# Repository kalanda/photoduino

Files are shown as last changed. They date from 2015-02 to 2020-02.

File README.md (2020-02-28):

           _                          _       _             
          | |           _            | |     (_)            
     ____ | |__   ___ _| |_  ___   __| |_   _ _ ____   ___  
    |  _ \|  _ \ / _ (_   _)/ _ \ / _  | | | | |  _ \ / _ \ 
    | |_| | | | | |_| || |_| |_| ( (_| | |_| | | | | | |_| |
    |  __/|_| |_|\___/  \__)\___/ \____|____/|_|_| |_|\___/ 
    |_|  THE OPENSOURCE CAMERA CONTROLLER BASED ON ARDUINO                                                         

https://kalanda.github.io/photoduino/

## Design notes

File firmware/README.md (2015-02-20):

           _                          _       _             
          | |           _            | |     (_)            
     ____ | |__   ___ _| |_  ___   __| |_   _ _ ____   ___  
    |  _ \|  _ \ / _ (_   _)/ _ \ / _  | | | | |  _ \ / _ \ 
    | |_| | | | | |_| || |_| |_| ( (_| | |_| | | | | | |_| |
    |  __/|_| |_|\___/  \__)\___/ \____|____/|_|_| |_|\___/ 
    |_|  THE OPENSOURCE CAMERA CONTROLLER BASED ON ARDUINO                                                         

#Photoduino firmware

Firmware for Photoduino Shield as Arduino Sketch.
[Download firmware release 1.1](http://sourceforge.net/projects/photoduino/files/firmware/photoduino.shield.firmware.v.1.1.zip/download)

* * *

##Firmware changelog:

## release 1.1

 - New sensor type "None" which is always triggered. This is useful when you want to use solenoid valve control without any barrier sensor.
 - Now the laser is always on if the "Device Type" is equal to "Laser" (laser will turn off when the photo is taken as usual)
 - Some changes related to the remote software
 - New language file with Francais translation of menus (Thanks to Guy Renou)

## release 1.0

 - Compatible with the new desktop software for remote control of Photoduino using USB port [Photoduino Remote Software](https://sourceforge.net/projects/photoduino/files/software/)
 - New language file with Italian translation of menus (Thanks to Andrea Candolini)

##release 0.10 

 - All files use ".ino" file extension for the 1.0 Arduino environment
 - Fixed some compile errors on Arduino 1.0 environment
 - Now uses progmem for allocating strings in program memory
 - Reduced compiled code size
 - New progress bar interface element
 - Added confirmation message when you reset config in any execution mode to avoid accidental losses
 - Fixed some spelling errors
 - Now the shutterlag is a common system parameter because it depends of the camera model and is the same in all the run modes. 
 - Now "Use flash1" and "Use flash2" are system parameters. If p.e. UseFlash2 is "NO", then in the config menus of all run modes you will don't see the "flash2 pretime".
 - Now, the language messages are in separated files for each language to improve future translations.
 - Mirror lockup timeout is now configurable through the system menu.
 - New system parameter "DEVICE TYPE" determines the use of the Device port like laser, electrovalve, ...
 - A big new functionality of control electro-valve or solenoid valve. Docs soon.
 - New key input holding A+B buttons to use it in numeric sensor tuning to match sensor and limit values to equal.

##release 0.9 

 - Added new "Mirror lockup" functionality in all sensor modes
 - Added new "Numeric mode" for tuning sensor limit with more precision. 
 - Added compatibility with ArduinoMega by "#define BOARD_ARDUINO_MEGA".
 - Default interval time is now 1 second instead 1000 miliseconds because 
   is more common used.
 - Added a compile value to define the pulse width for shooting the flash.
 - Some other minor fixes and code reviews.  
 
##release 0.8

 - Bug fixed on some cameras like canon 50d with prebulb yes. 
 
##release 0.7 

 - Bug fixed on shutterEnd with prebulb yes. 
  
##release 0.6 

 - New mode "Flash slave" uses the LDR sensor to shoot the flashes like a 
   slave flash.
 - Now all text messages are defines to make posible the i18n. 
   Current available languages are spanish and english
 - Fixed a bug with cycles on intervalmode
 
##release 0.5 

 - Now each sensor have a run mode and custom config
 - New parameter "cycles" also on sensor trigger modes
 - New parameter "intercicle time" added on sensor trigger modes for wait
   between cycles to let the camera time to process the photo or avoid shoots
   by noise on sensors.
 - Removed all "exit" options from menus to reduce code size and simplify. 
   Use hold-A-button to exit.
 - Added power on/off control of a laser connected to the RESERVED port. 
   Laser is set power-off before open the camera shutter.
 - Re-organization of .pde files
 - Many code improvements to reduce code size and enhace the organization
 
##release 0.4

 - Keyboard reading is completly re-writed code to enhance control and use 
   debounce and hold time
 - Revision of code comments
 - added reference of default shutterlag times for canon DSLR cameras
 - (function setSensorLimit) now uses two buttons for up and down the value
  
##release 0.3

 - (function setIntValue) Bug fixed when sets numeric values higher than 59999 
 - (function setIntValue) Numeric values now uses two buttons for up and down 
 - (function setIntValue) Now shows the measure units
 - (PINS_BTN_A and PINS_BTN_B) Interchanged to be the same reference in silkscreen
 - (function keyScan) Bug fixed
 
##release 0.2

 - New file organization
 - Various improvements
 - Configuration backup on eeprom

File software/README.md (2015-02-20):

           _                          _       _             
          | |           _            | |     (_)            
     ____ | |__   ___ _| |_  ___   __| |_   _ _ ____   ___  
    |  _ \|  _ \ / _ (_   _)/ _ \ / _  | | | | |  _ \ / _ \ 
    | |_| | | | | |_| || |_| |_| ( (_| | |_| | | | | | |_| |
    |  __/|_| |_|\___/  \__)\___/ \____|____/|_|_| |_|\___/ 
    |_|  THE OPENSOURCE CAMERA CONTROLLER BASED ON ARDUINO                                                         

#Photoduino remote

This is the repository for souce code of Photoduino Remote, a desktop application for remote control of Photoduino hardware using the USB cable.

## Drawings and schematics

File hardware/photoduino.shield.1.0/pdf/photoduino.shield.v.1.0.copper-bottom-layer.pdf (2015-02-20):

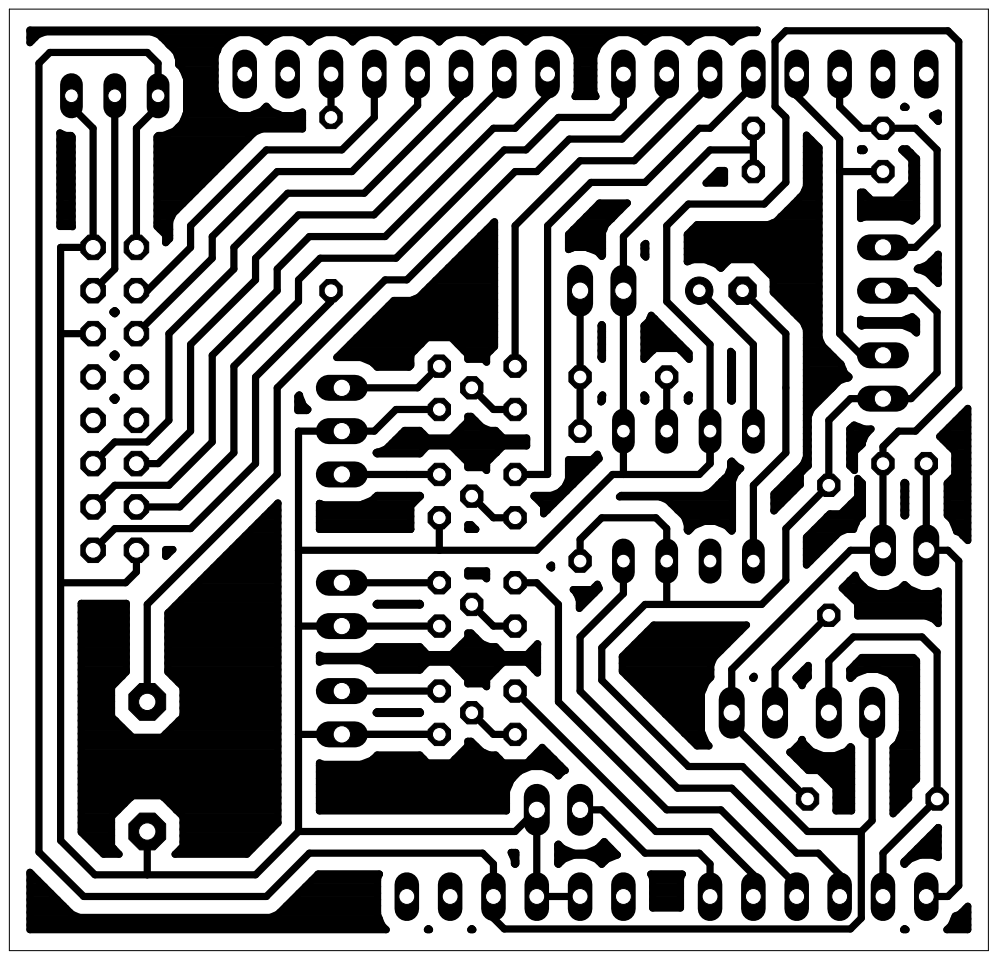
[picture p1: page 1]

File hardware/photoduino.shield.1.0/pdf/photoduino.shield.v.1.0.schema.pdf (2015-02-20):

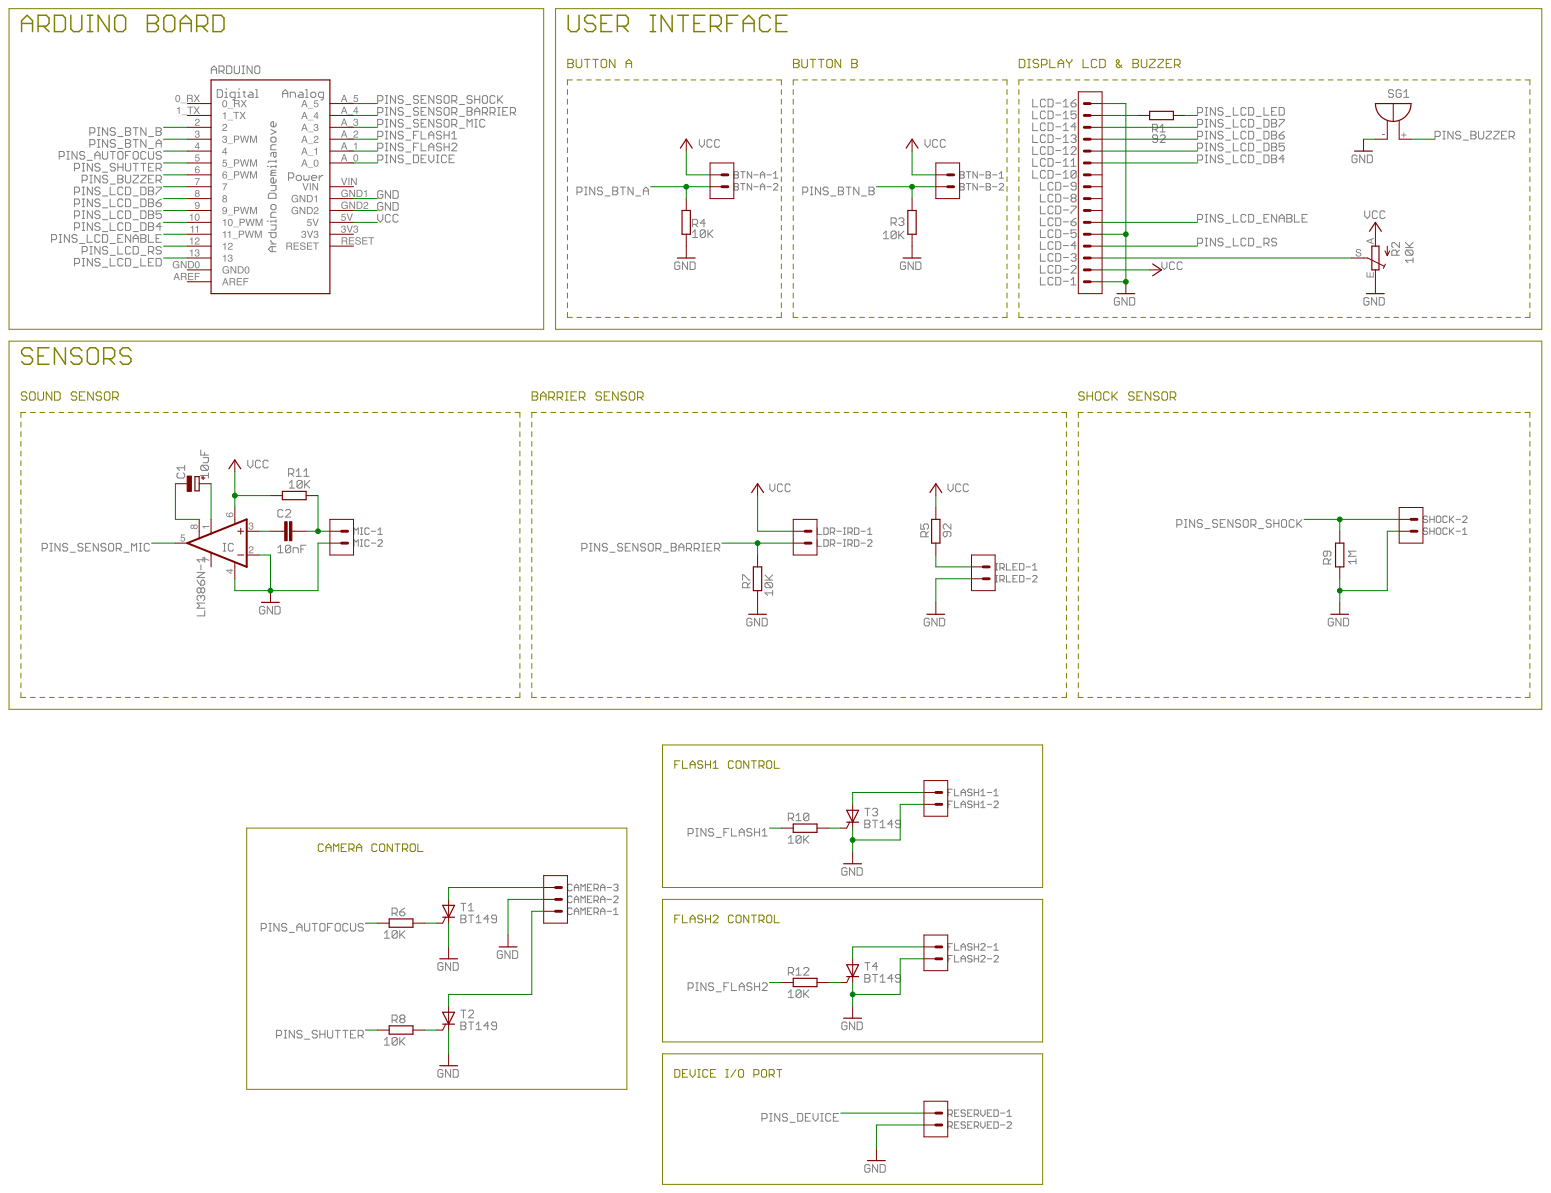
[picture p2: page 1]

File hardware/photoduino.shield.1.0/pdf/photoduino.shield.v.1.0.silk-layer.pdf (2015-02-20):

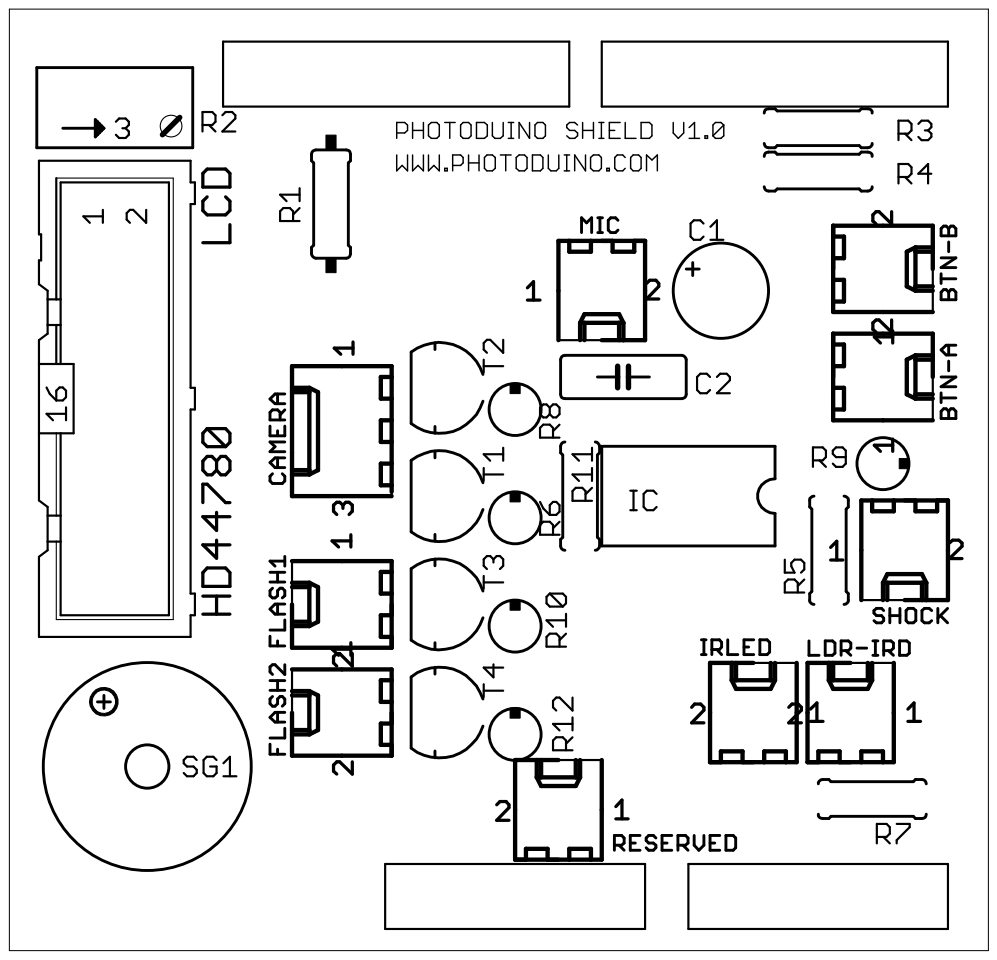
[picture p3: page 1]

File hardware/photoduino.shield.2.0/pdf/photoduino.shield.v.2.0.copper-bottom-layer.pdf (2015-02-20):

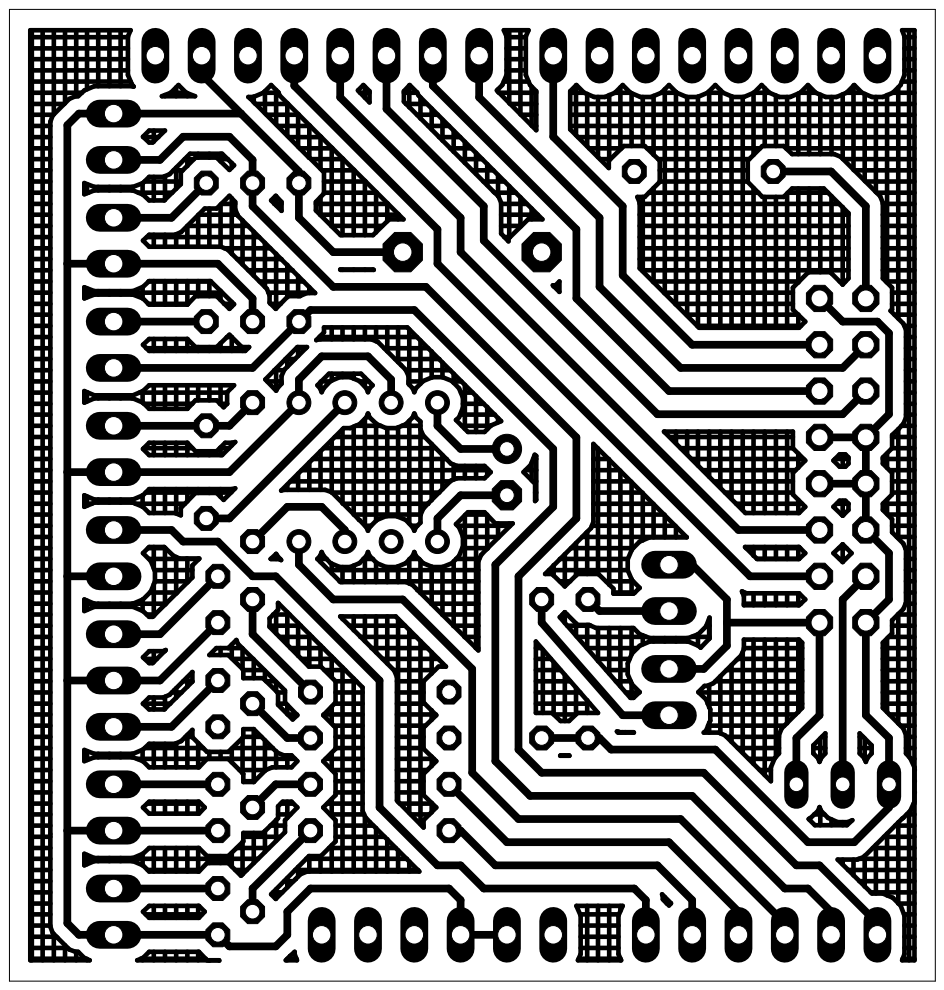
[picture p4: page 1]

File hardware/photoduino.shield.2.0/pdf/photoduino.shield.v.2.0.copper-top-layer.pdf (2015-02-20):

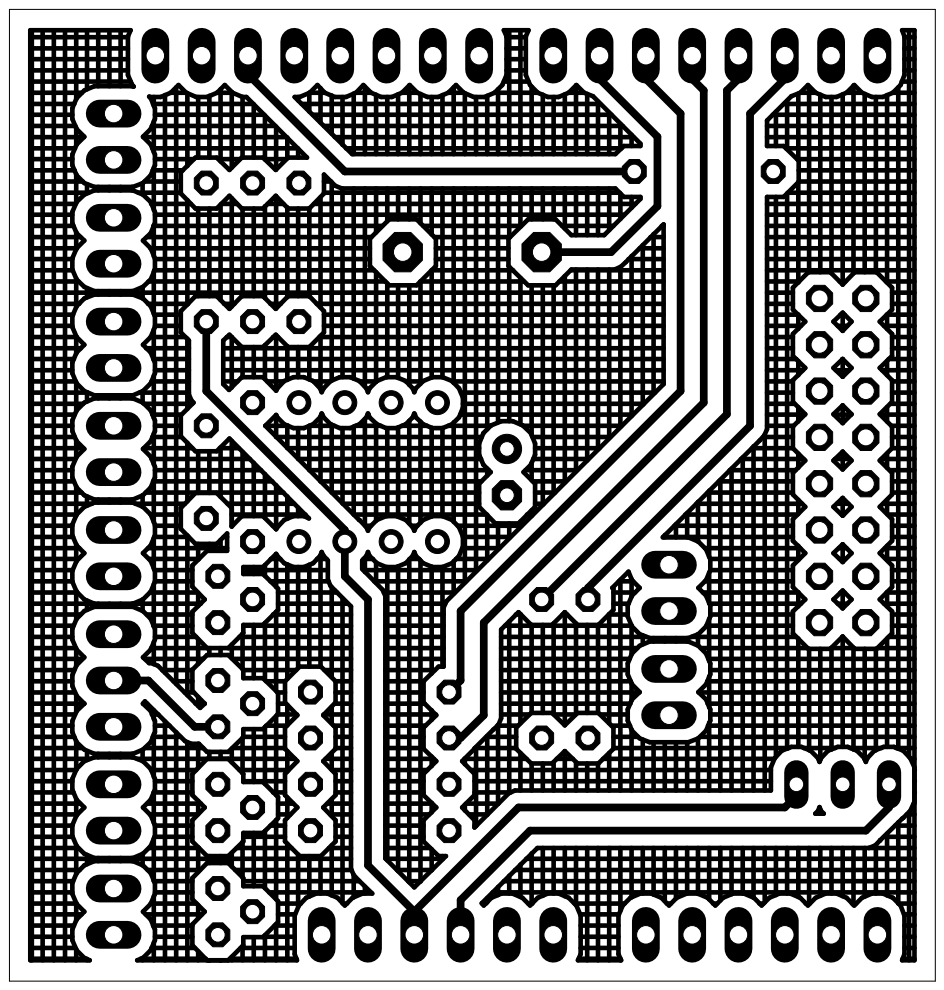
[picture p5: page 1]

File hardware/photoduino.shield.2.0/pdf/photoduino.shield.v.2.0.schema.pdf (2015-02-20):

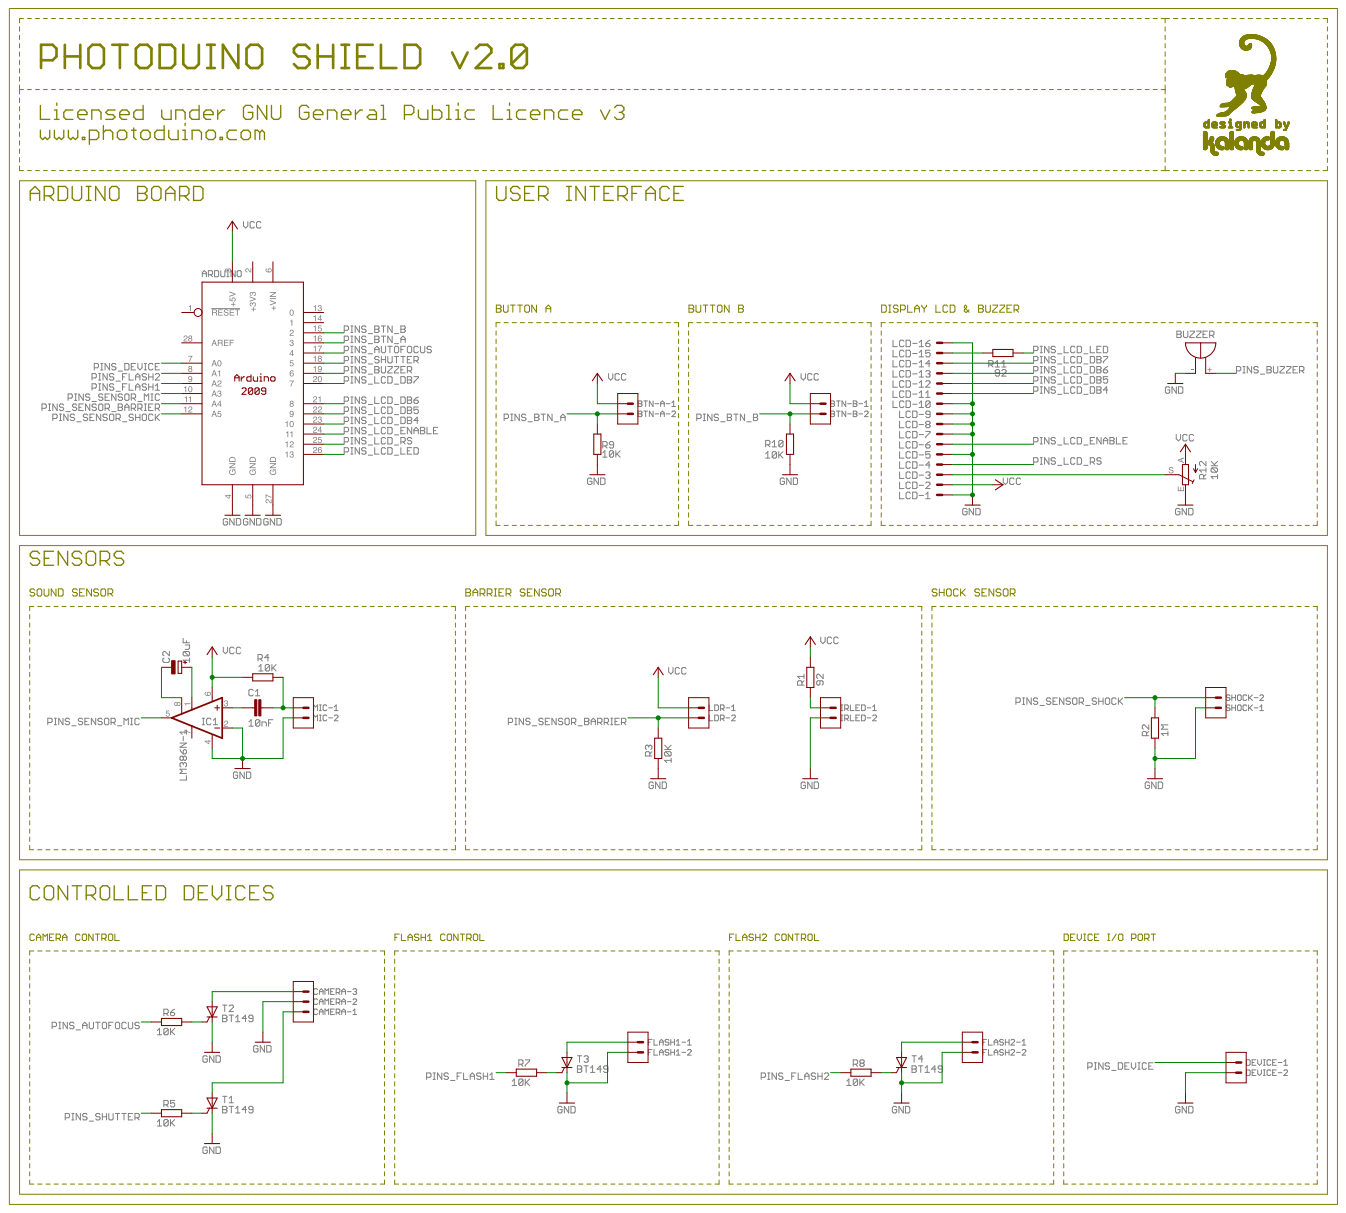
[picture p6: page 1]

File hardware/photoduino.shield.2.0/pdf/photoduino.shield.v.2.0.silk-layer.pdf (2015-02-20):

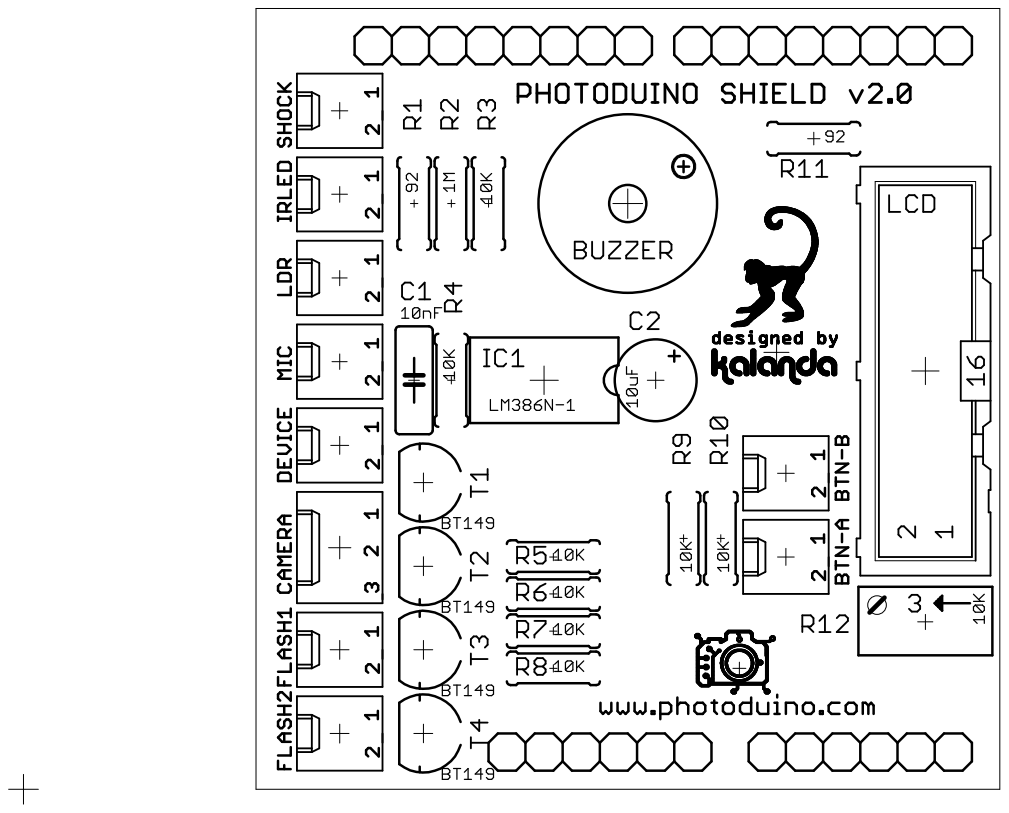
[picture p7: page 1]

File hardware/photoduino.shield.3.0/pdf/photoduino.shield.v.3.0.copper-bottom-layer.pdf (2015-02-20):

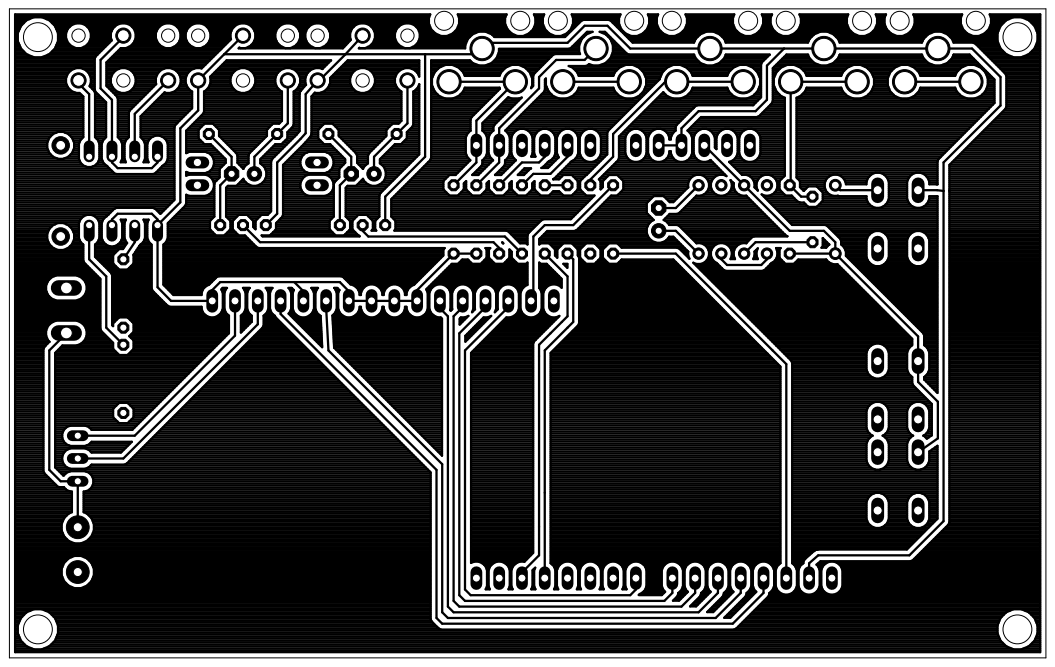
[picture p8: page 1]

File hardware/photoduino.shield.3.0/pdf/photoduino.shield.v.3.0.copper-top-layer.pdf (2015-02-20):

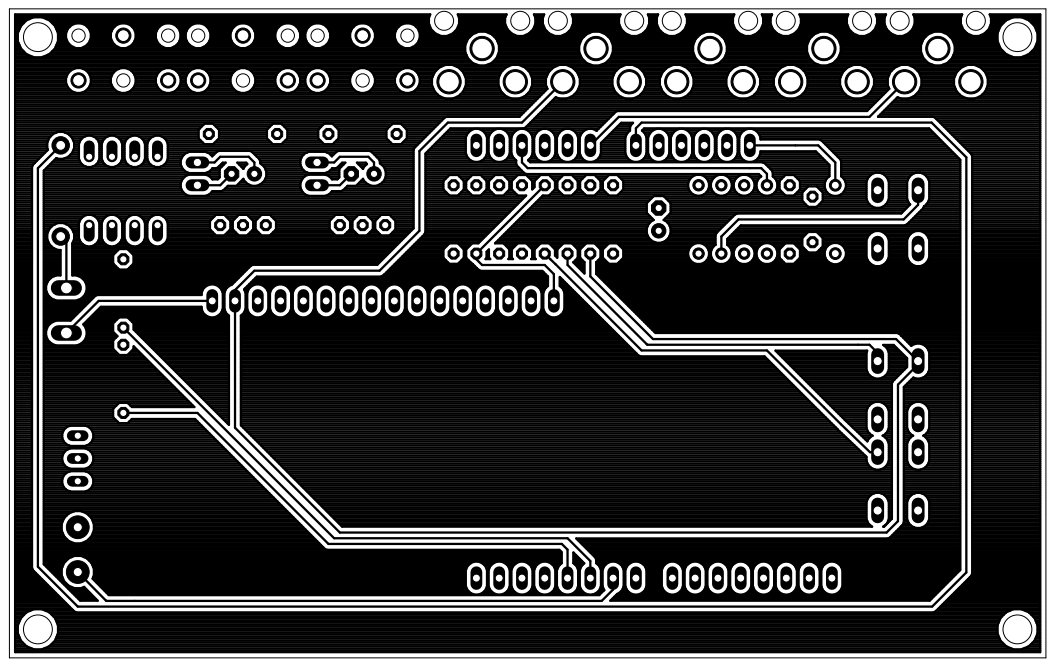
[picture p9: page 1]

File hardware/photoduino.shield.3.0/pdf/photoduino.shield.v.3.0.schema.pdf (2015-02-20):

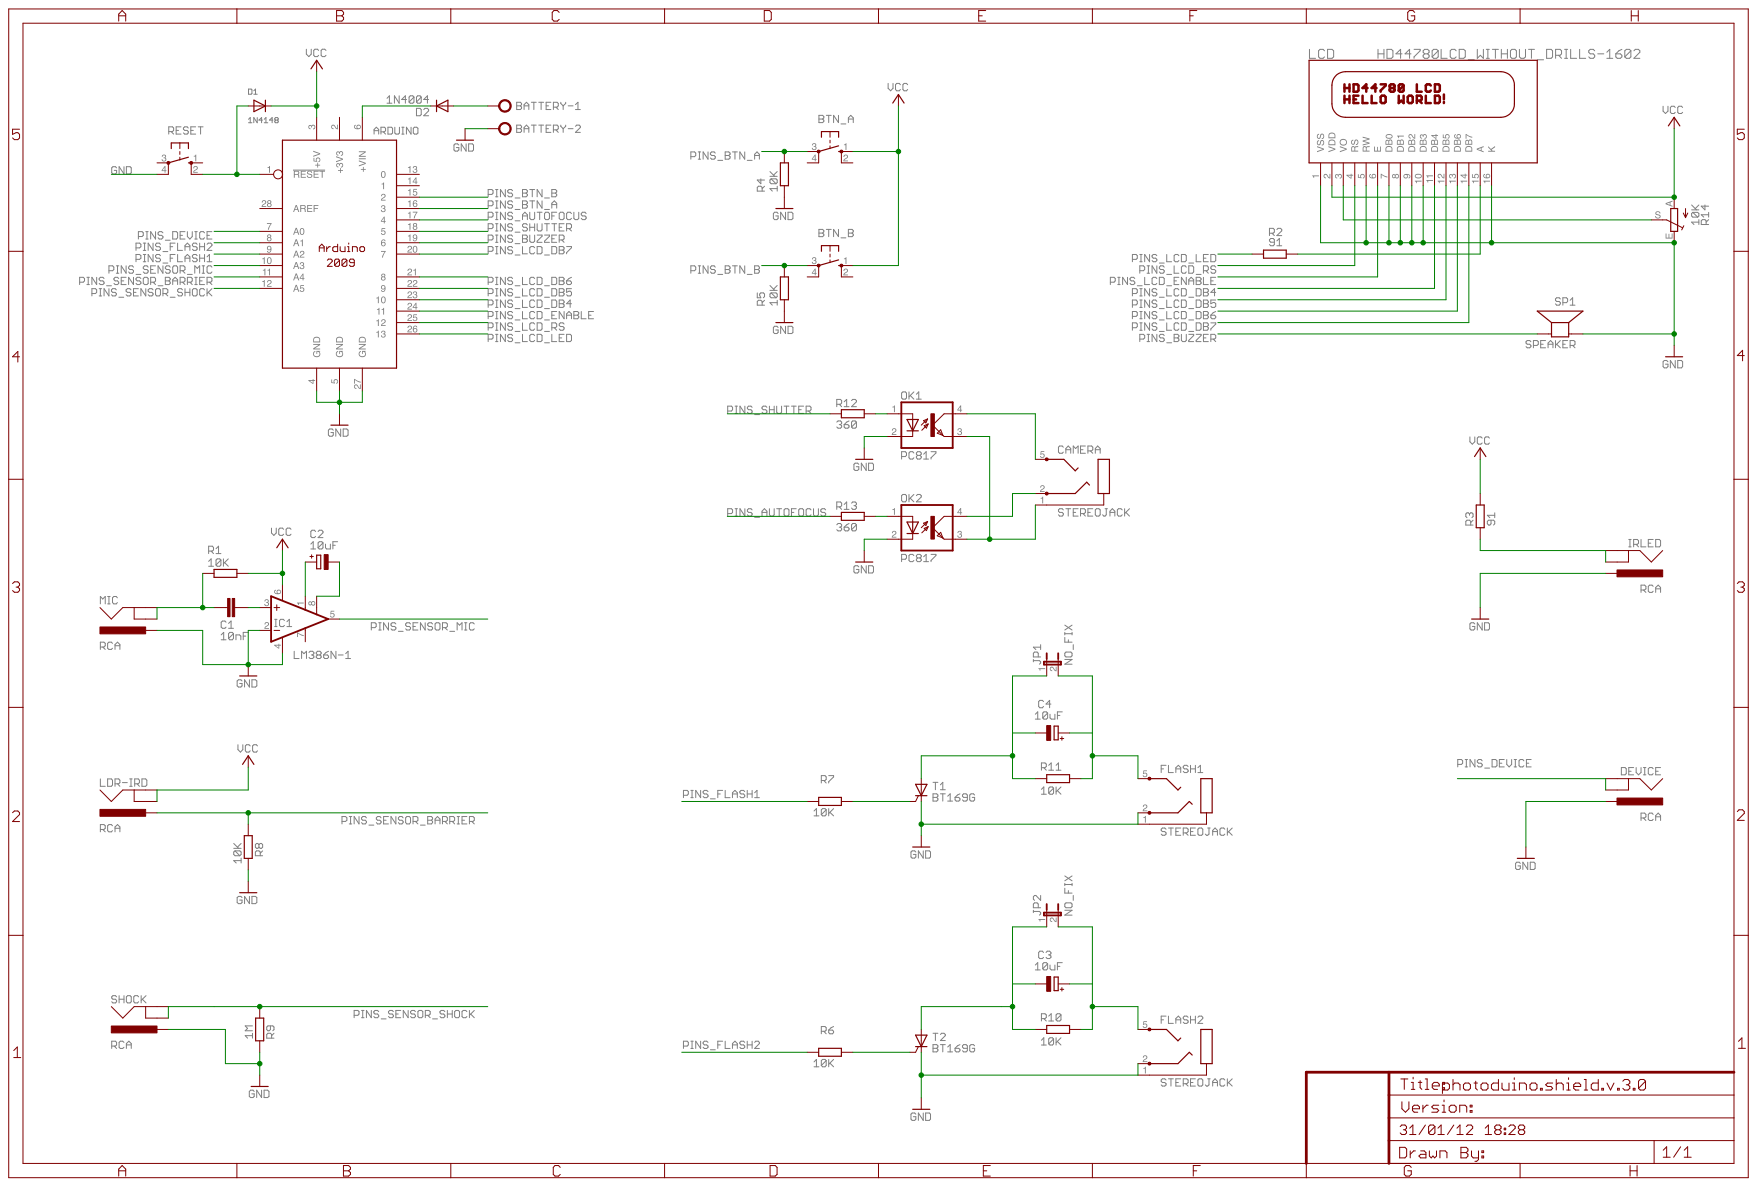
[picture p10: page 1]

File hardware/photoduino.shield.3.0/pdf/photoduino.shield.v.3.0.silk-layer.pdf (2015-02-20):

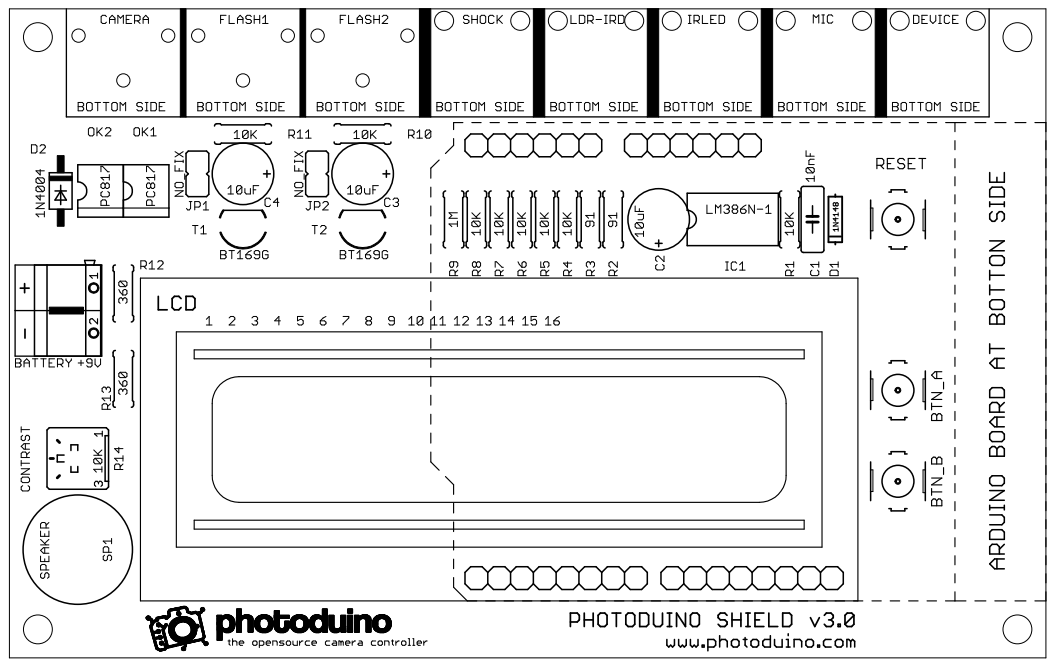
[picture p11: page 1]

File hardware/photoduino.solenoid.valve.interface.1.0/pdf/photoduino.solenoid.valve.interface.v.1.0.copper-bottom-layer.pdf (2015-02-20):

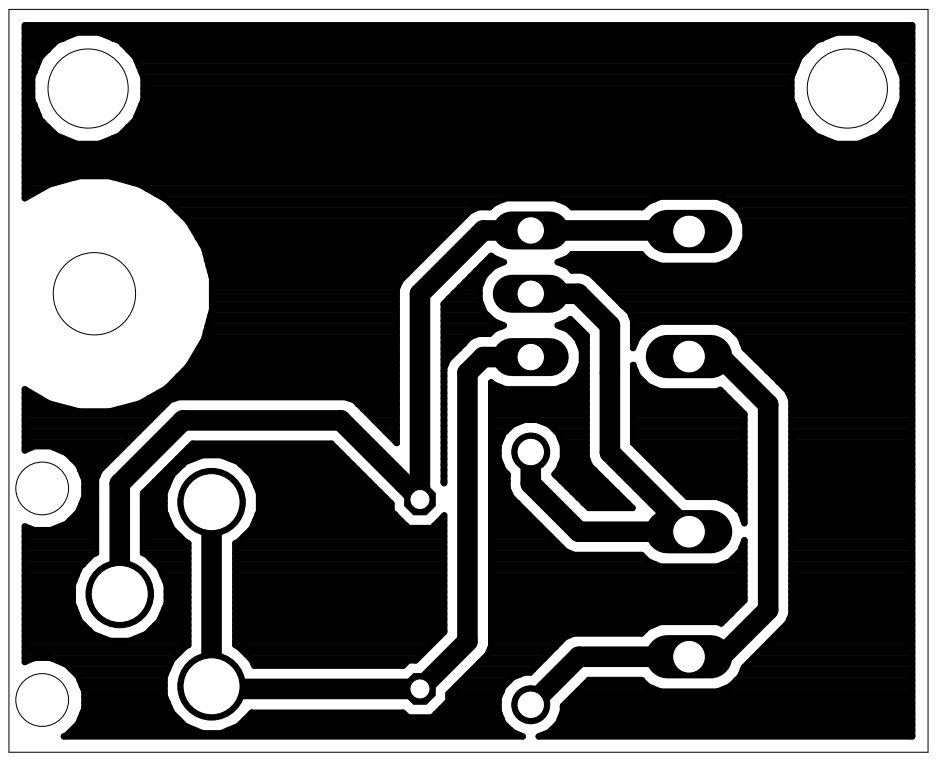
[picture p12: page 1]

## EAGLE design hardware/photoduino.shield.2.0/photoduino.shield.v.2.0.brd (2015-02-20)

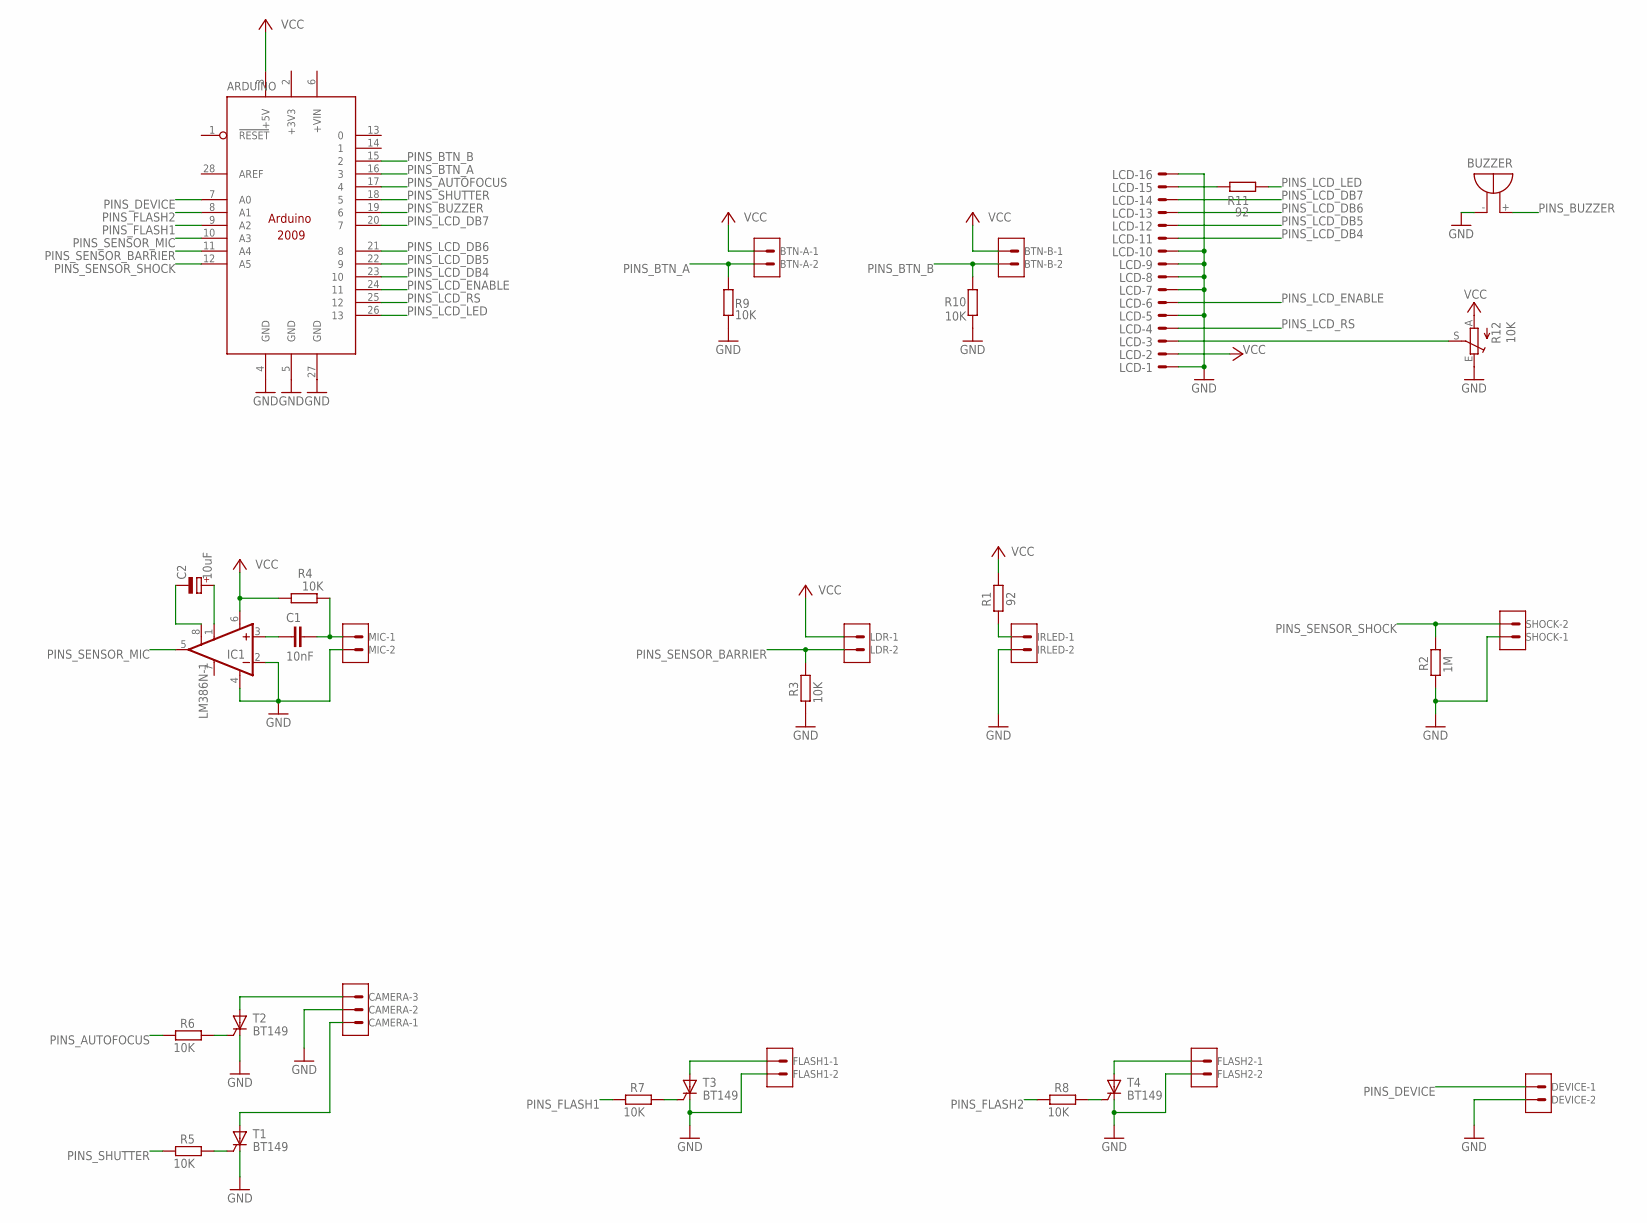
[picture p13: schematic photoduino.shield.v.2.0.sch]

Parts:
ARDUINO: ARDUINO2009_11; ARDUINO2009_1
BTN-A: 22-27-2021-02; 6410-02
BTN-B: 22-27-2021-02; 6410-02
BUZZER: F/TMB
C1: 10nF; C050-025X075
C2: 10uF; E2,5-6
CAMERA: 22-27-2031-03; 6410-03
DEVICE: 22-27-2021-02; 6410-02
FLASH1, FLASH2: 22-27-2021-02; 6410-02
IC1: LM386N-1; DIL08
IRLED: 22-27-2021-02; 6410-02
LCD: ML16E; ML16
LDR: 22-27-2021-02; 6410-02
LOGO: LOGOKALANDA
MIC: 22-27-2021-02; 6410-02
R1, R11: 92; 0207/7
R2: 1M; 0207/7
R3, R4, R5, R6, R7, R8, R9, R10: 10K; 0207/7
R12: 10K; RJ9W
SHOCK: 22-27-2021-02; 6410-02
T1, T2, T3, T4: BT149; TO92-4

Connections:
+3V3: ARDUINO.2 (+3V3)
GND: ARDUINO.4 (GND), ARDUINO.5 (GND), ARDUINO.27 (GND), BUZZER.-, CAMERA.2, DEVICE.2, FLASH1.2, FLASH2.2, IC1.2 (-IN), IC1.4 (GND), IRLED.2, LCD.1, LCD.5, LCD.7, LCD.8, LCD.9, LCD.10, LCD.16, MIC.2, R2.2, R3.2, R9.1, R10.2, R12.E, SHOCK.1, T1.C, T2.C, T3.C, T4.C
LCD_CONTRAST: LCD.3, R12.S
unnamed: IRLED.1, R1.2
unnamed: C1.1, IC1.3 (+IN)
unnamed: C1.2, MIC.1, R4.1
unnamed: R7.1, T3.G
unnamed: R8.1, T4.G
unnamed: CAMERA.3, T2.A
unnamed: R6.1, T2.G
unnamed: R5.1, T1.G
unnamed: C2.+, IC1.1 (GAIN)
unnamed: FLASH2.1, T4.A
unnamed: FLASH1.1, T3.A
unnamed: C2.-, IC1.8 (GAIN)
unnamed: LCD.15, R11.2
PINS_AUTOFOCUS: ARDUINO.17 (4), R6.2
PINS_BTN_A: ARDUINO.16 (3), BTN-A.2, R9.2
PINS_BTN_B: ARDUINO.15 (2), BTN-B.2, R10.1
PINS_BUZZER: ARDUINO.19 (6), BUZZER.+
PINS_DEVICE: ARDUINO.7 (A0), DEVICE.1
PINS_FLASH1: ARDUINO.9 (A2), R7.2
PINS_FLASH2: ARDUINO.8 (A1), R8.2
PINS_LCD_DB4: ARDUINO.23 (10), LCD.11
PINS_LCD_DB5: ARDUINO.22 (9), LCD.12
PINS_LCD_DB6: ARDUINO.21 (8), LCD.13
PINS_LCD_DB7: ARDUINO.20 (7), LCD.14
PINS_LCD_ENABLE: ARDUINO.24 (11), LCD.6
PINS_LCD_LED: ARDUINO.26 (13), R11.1
PINS_LCD_RS: ARDUINO.25 (12), LCD.4
PINS_SENSOR_BARRIER: ARDUINO.11 (A4), LDR.2, R3.1
PINS_SENSOR_MIC: ARDUINO.10 (A3), IC1.5 (OUT)
PINS_SENSOR_SHOCK: ARDUINO.12 (A5), R2.1, SHOCK.2
PINS_SHUTTER: ARDUINO.18 (5), R5.2
SHUTTER: CAMERA.1, T1.A
VCC: ARDUINO.3 (+5V), BTN-A.1, BTN-B.1, IC1.6 (VS), LCD.2, LDR.1, R1.1, R4.2, R12.A

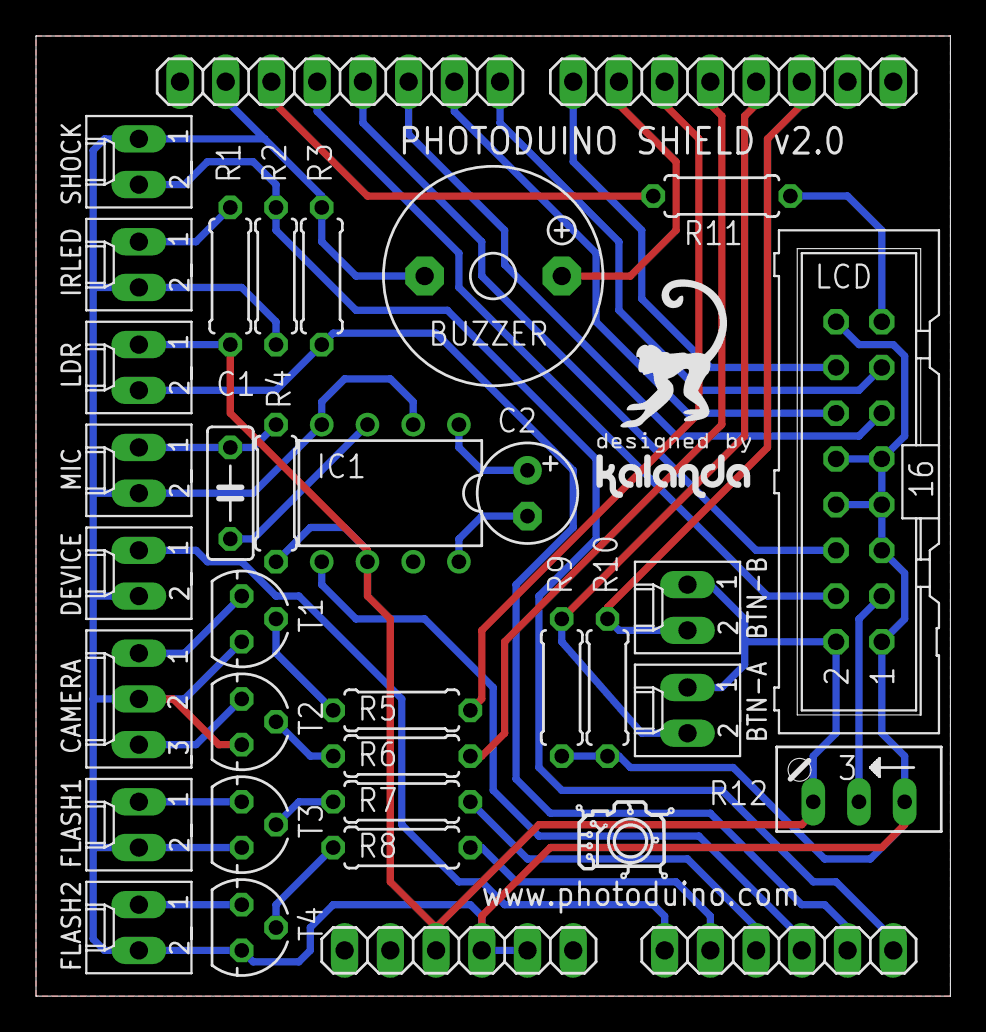
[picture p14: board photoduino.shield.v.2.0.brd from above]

Board: 2 copper layers, 50.8 x 53.3 mm, 34 parts (0 on the bottom side), 35 nets.

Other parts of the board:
U$1: LOGOPHOTODUINO

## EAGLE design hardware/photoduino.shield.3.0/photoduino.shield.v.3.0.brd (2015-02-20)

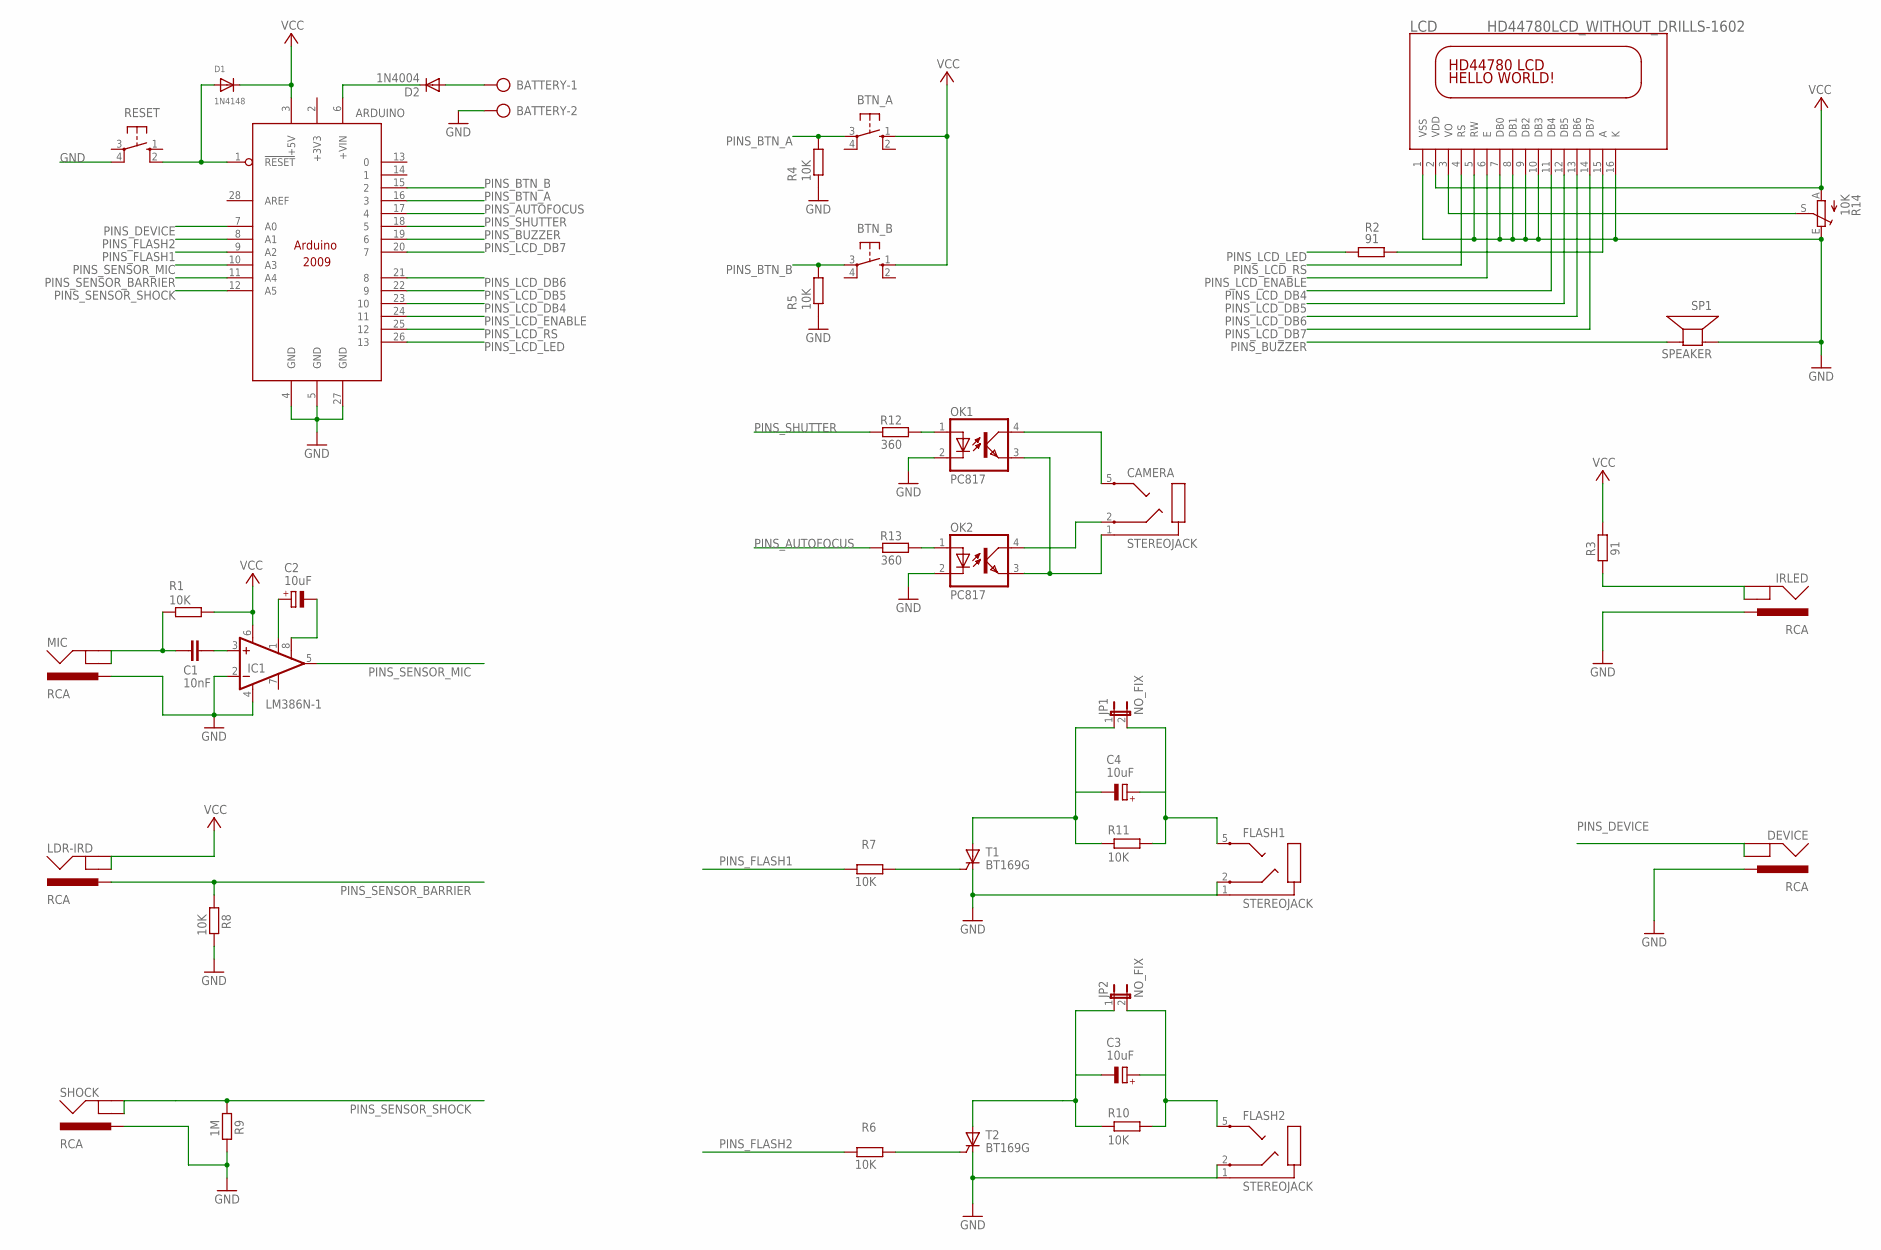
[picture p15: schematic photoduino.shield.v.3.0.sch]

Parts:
ARDUINO: ARDUINO2009_12; ARDUINO2009_2
BATTERY: AK500/2
BTN_A: 10-XX; B3F-10XX
BTN_B: 10-XX; B3F-10XX
C1: 10nF; C050-025X075
C2, C3, C4: 10uF; E2,5-7
CAMERA: STEREOJACK; STX3100-3N
D1: 1N4148; DO-1N4148
D2: 1N4004; DO41-10
DEVICE: RCA; RCA_4UCON
FLASH1, FLASH2: STEREOJACK; STX3100-3N
IC1: LM386N-1; DIL08
IRLED: RCA; RCA_4UCON
JP1, JP2: NO_FIX; JP1
LCD: HD44780LCD_WITHOUT_DRILLS-1602; LCD1602
LDR-IRD: RCA; RCA_4UCON
MIC: RCA; RCA_4UCON
OK1, OK2: PC817; DIL04
R1, R4, R5, R6, R7, R8, R10, R11: 10K; 0207/7
R2, R3: 91; 0207/7
R9: 1M; 0207/7
R12, R13: 360; 0207/7
R14: 10K; B25U
RESET: 10-XX; B3F-10XX
SHOCK: RCA; RCA_4UCON
SP1: SPEAKER; PS12
T1, T2: BT169G; TO92-2

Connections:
+3V3: ARDUINO.2 (+3V3)
GND: ARDUINO.4 (GND), ARDUINO.5 (GND), ARDUINO.27 (GND), BATTERY.2, DEVICE.BARREL, FLASH1.1, FLASH1.2, FLASH2.1, FLASH2.2, IC1.2 (-IN), IC1.4 (GND), IRLED.BARREL, LCD.1 (VSS), LCD.5 (RW), LCD.7 (DB0), LCD.8 (DB1), LCD.9 (DB2), LCD.10 (DB3), LCD.16 (K), MIC.BARREL, OK1.2 (C), OK2.2 (C), R4.1, R5.1, R8.2, R9.2, R14.E, RESET.4 (P1), SHOCK.BARREL, SP1.P$1 (+), T1.C, T2.C
LCD_CONTRAST: LCD.3 (VO), R14.S
unnamed: IRLED.BREAK, IRLED.SPRING, R3.2
unnamed: CAMERA.1, OK1.3 (EMIT), OK2.3 (EMIT)
unnamed: C4.+, FLASH1.5, JP1.2, R11.2
unnamed: R6.1, T2.G
unnamed: ARDUINO.1 (!RESET), D1.A, RESET.2 (S1)
unnamed: C4.-, JP1.1, R11.1, T1.A
unnamed: C3.+, FLASH2.5, JP2.2, R10.2
unnamed: C3.-, JP2.1, R10.1, T2.A
unnamed: ARDUINO.6 (+VIN), D2.C
unnamed: C1.1, IC1.3 (+IN)
unnamed: BATTERY.1, D2.A
unnamed: C1.2, MIC.BREAK, MIC.SPRING, R1.1
unnamed: R7.1, T1.G
unnamed: CAMERA.5, OK1.4 (COL)
unnamed: OK1.1 (A), R12.1
unnamed: OK2.1 (A), R13.1
unnamed: C2.+, IC1.1 (GAIN)
unnamed: C2.-, IC1.8 (GAIN)
unnamed: LCD.15 (A), R2.1
PINS_AUTOFOCUS: ARDUINO.17 (4), R13.2
PINS_BTN_A: ARDUINO.16 (3), BTN_A.3, R4.2
PINS_BTN_B: ARDUINO.15 (2), BTN_B.3, R5.2
PINS_BUZZER: ARDUINO.19 (6), SP1.P$2 (-)
PINS_DEVICE: ARDUINO.7 (A0), DEVICE.BREAK, DEVICE.SPRING
PINS_FLASH1: ARDUINO.9 (A2), R7.2
PINS_FLASH2: ARDUINO.8 (A1), R6.2
PINS_LCD_DB4: ARDUINO.23 (10), LCD.11 (DB4)
PINS_LCD_DB5: ARDUINO.22 (9), LCD.12 (DB5)
PINS_LCD_DB6: ARDUINO.21 (8), LCD.13 (DB6)
PINS_LCD_DB7: ARDUINO.20 (7), LCD.14 (DB7)
PINS_LCD_ENABLE: ARDUINO.24 (11), LCD.6 (E)
PINS_LCD_LED: ARDUINO.26 (13), R2.2
PINS_LCD_RS: ARDUINO.25 (12), LCD.4 (RS)
PINS_SENSOR_BARRIER: ARDUINO.11 (A4), LDR-IRD.BARREL, R8.1
PINS_SENSOR_MIC: ARDUINO.10 (A3), IC1.5 (OUT)
PINS_SENSOR_SHOCK: ARDUINO.12 (A5), R9.1, SHOCK.BREAK, SHOCK.SPRING
PINS_SHUTTER: ARDUINO.18 (5), R12.2
SHUTTER: CAMERA.2, OK2.4 (COL)
VCC: ARDUINO.3 (+5V), BTN_A.1 (S), BTN_B.1 (S), D1.C, IC1.6 (VS), LCD.2 (VDD), LDR-IRD.BREAK, LDR-IRD.SPRING, R1.2, R3.1, R14.A

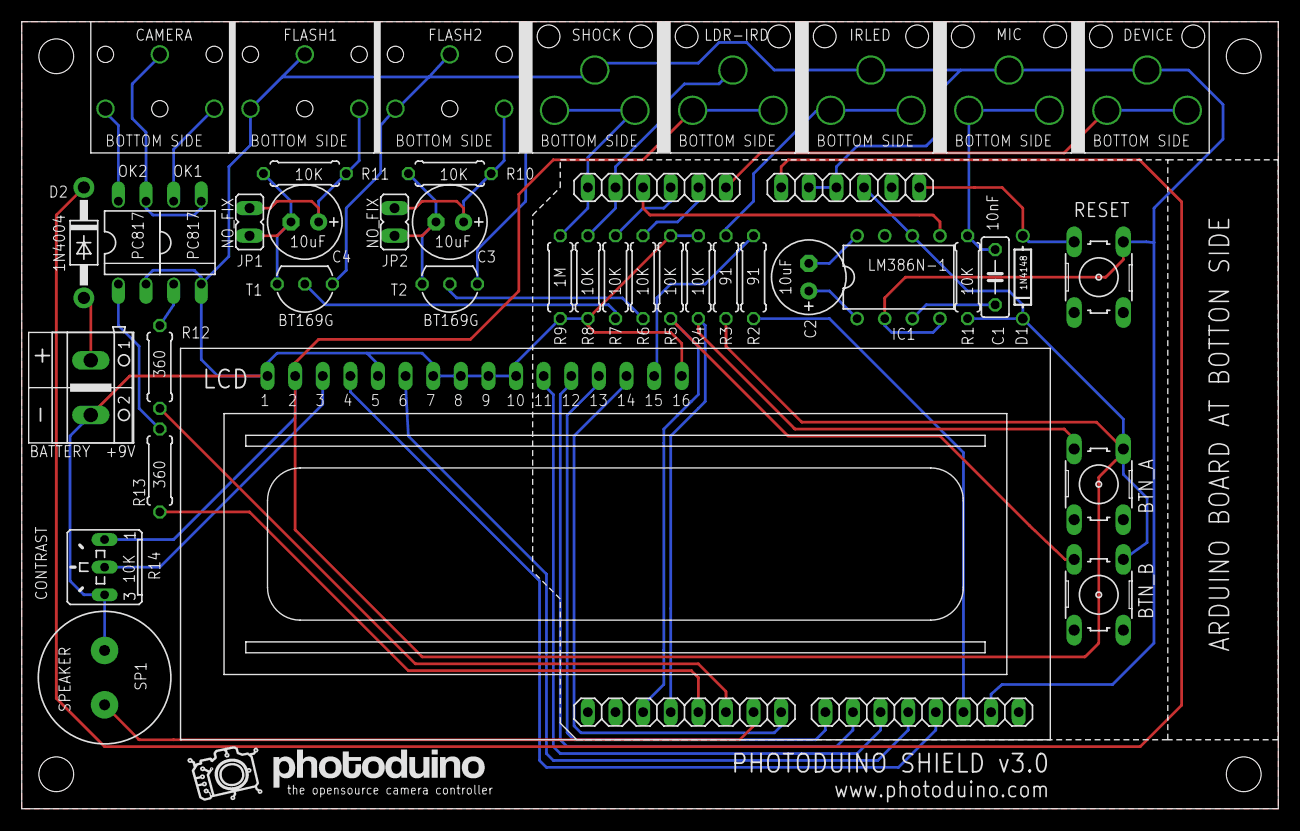
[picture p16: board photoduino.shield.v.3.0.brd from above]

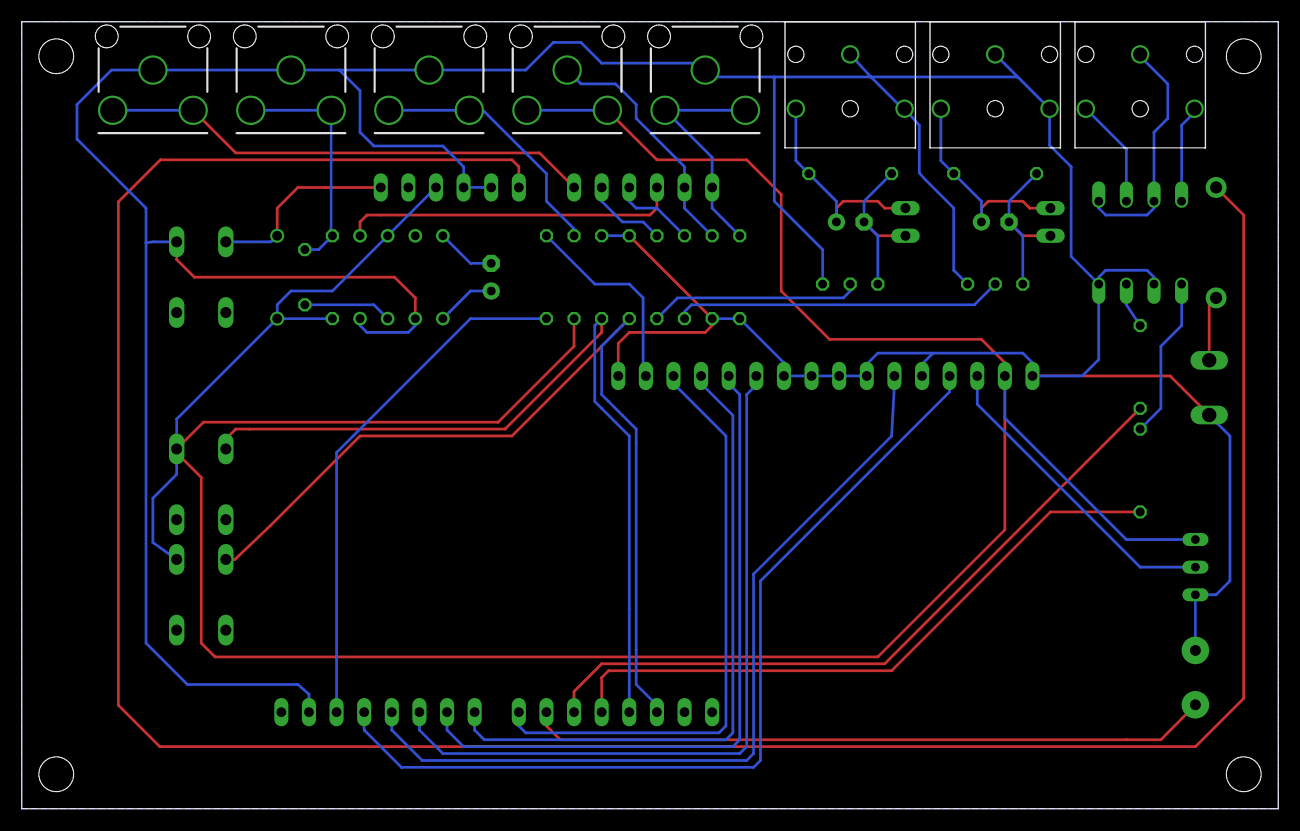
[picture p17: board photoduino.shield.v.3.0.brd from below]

Board: 2 copper layers, 115.6 x 72.4 mm, 43 parts (8 on the bottom side), 41 nets.

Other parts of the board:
U$2: LOGOPHOTODUINO2

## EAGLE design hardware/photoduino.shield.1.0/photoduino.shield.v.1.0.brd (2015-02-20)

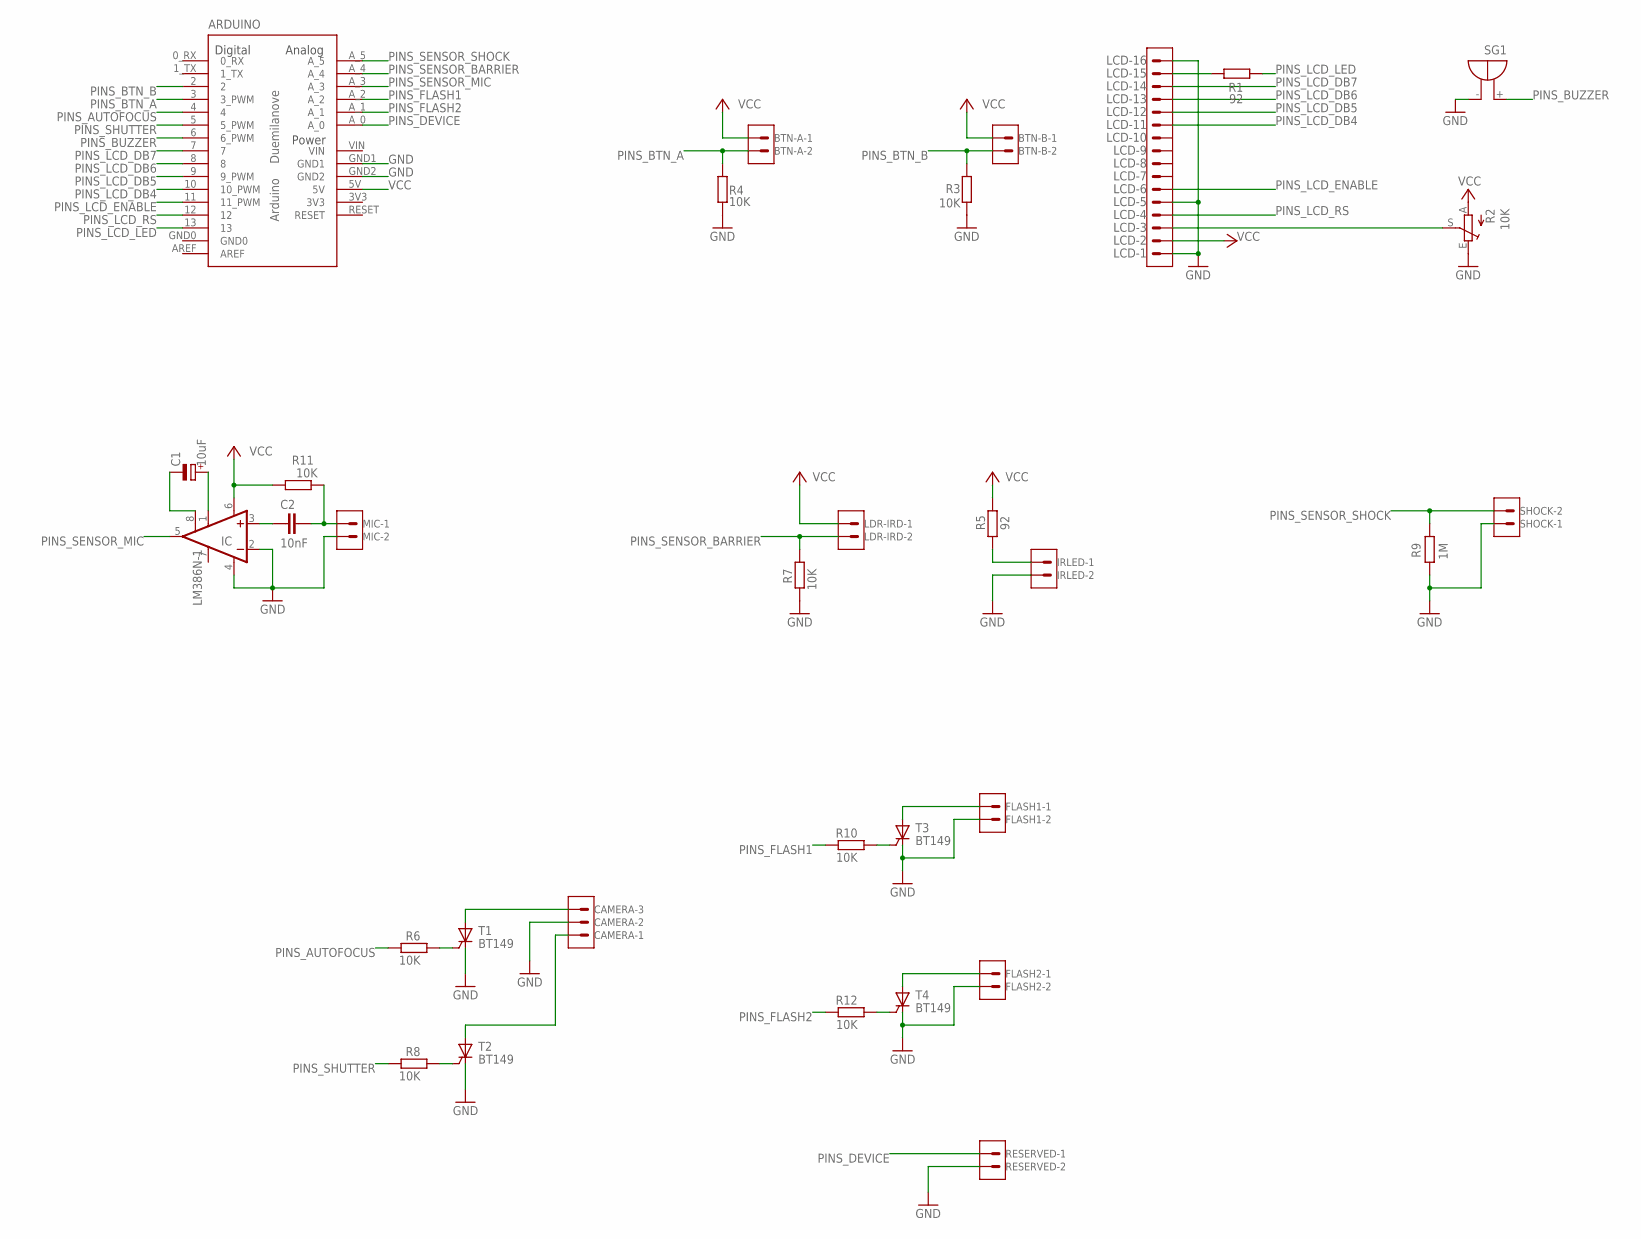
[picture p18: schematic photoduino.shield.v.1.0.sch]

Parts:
ARDUINO: ARDUINO-USBNO-OUTLINE-NO-TEXT-OCTAGONAL; NO-OUTLINE-OCTAGONAL-NOTEXT
BTN-A: 22-27-2021-02; 6410-02
BTN-B: 22-27-2021-02; 6410-02
C1: 10uF; E2,5-6
C2: 10nF; C050-025X075
CAMERA: 22-27-2031-03; 6410-03
FLASH1, FLASH2: 22-27-2021-02; 6410-02
IC: LM386N-1; DIL08
IRLED: 22-27-2021-02; 6410-02
LCD: HD44780; ML16
LDR-IRD: 22-27-2021-02; 6410-02
MIC: 22-27-2021-02; 6410-02
R1: 92; 0207/10
R2: 10K; RJ9W
R3, R4, R7, R11: 10K; 0207/7
R5: 92; 0207/7
R6, R8, R10, R12: 10K; 0309V
R9: 1M; 0309V
RESERVED: 22-27-2021-02; 6410-02
SG1: F/TMB
SHOCK: 22-27-2021-02; 6410-02
T1, T2, T3, T4: BT149; TO92-4

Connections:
3V3: ARDUINO.3V3
GND: ARDUINO.GND1, ARDUINO.GND2, CAMERA.2, FLASH1.2, FLASH2.2, IC.2 (-IN), IC.4 (GND), IRLED.2, LCD.1, LCD.5, LCD.16, MIC.2, R2.E, R3.2, R4.1, R7.2, R9.1, RESERVED.2, SG1.-, SHOCK.1, T1.C, T2.C, T3.C, T4.C
LCD_CONTRAST: LCD.3, R2.S
unnamed: C2.1, IC.3 (+IN)
unnamed: C2.2, MIC.1, R11.1
unnamed: IRLED.1, R5.1
unnamed: R10.1, T3.G
unnamed: R12.1, T4.G
unnamed: CAMERA.3, T1.A
unnamed: R6.1, T1.G
unnamed: R8.1, T2.G
unnamed: C1.+, IC.1 (GAIN)
unnamed: FLASH2.1, T4.A
unnamed: FLASH1.1, T3.A
unnamed: C1.-, IC.8 (GAIN)
unnamed: LCD.15, R1.2
PINS_AUTOFOCUS: ARDUINO.4, R6.2
PINS_BTN_A: ARDUINO.3 (3_PWM), BTN-A.2, R4.2
PINS_BTN_B: ARDUINO.2, BTN-B.2, R3.1
PINS_BUZZER: ARDUINO.6 (6_PWM), SG1.+
PINS_DEVICE: ARDUINO.A_0, RESERVED.1
PINS_FLASH1: ARDUINO.A_2, R10.2
PINS_FLASH2: ARDUINO.A_1, R12.2
PINS_LCD_DB4: ARDUINO.10 (10_PWM), LCD.11
PINS_LCD_DB5: ARDUINO.9 (9_PWM), LCD.12
PINS_LCD_DB6: ARDUINO.8, LCD.13
PINS_LCD_DB7: ARDUINO.7, LCD.14
PINS_LCD_ENABLE: ARDUINO.11 (11_PWM), LCD.6
PINS_LCD_LED: ARDUINO.13, R1.1
PINS_LCD_RS: ARDUINO.12, LCD.4
PINS_SENSOR_BARRIER: ARDUINO.A_4, LDR-IRD.2, R7.1
PINS_SENSOR_MIC: ARDUINO.A_3, IC.5 (OUT)
PINS_SENSOR_SHOCK: ARDUINO.A_5, R9.2, SHOCK.2
PINS_SHUTTER: ARDUINO.5 (5_PWM), R8.2
SHUTTER: CAMERA.1, T2.A
VCC: ARDUINO.5V, BTN-A.1, BTN-B.1, IC.6 (VS), LCD.2, LDR-IRD.1, R2.A, R5.2, R11.2
VIN: ARDUINO.VIN

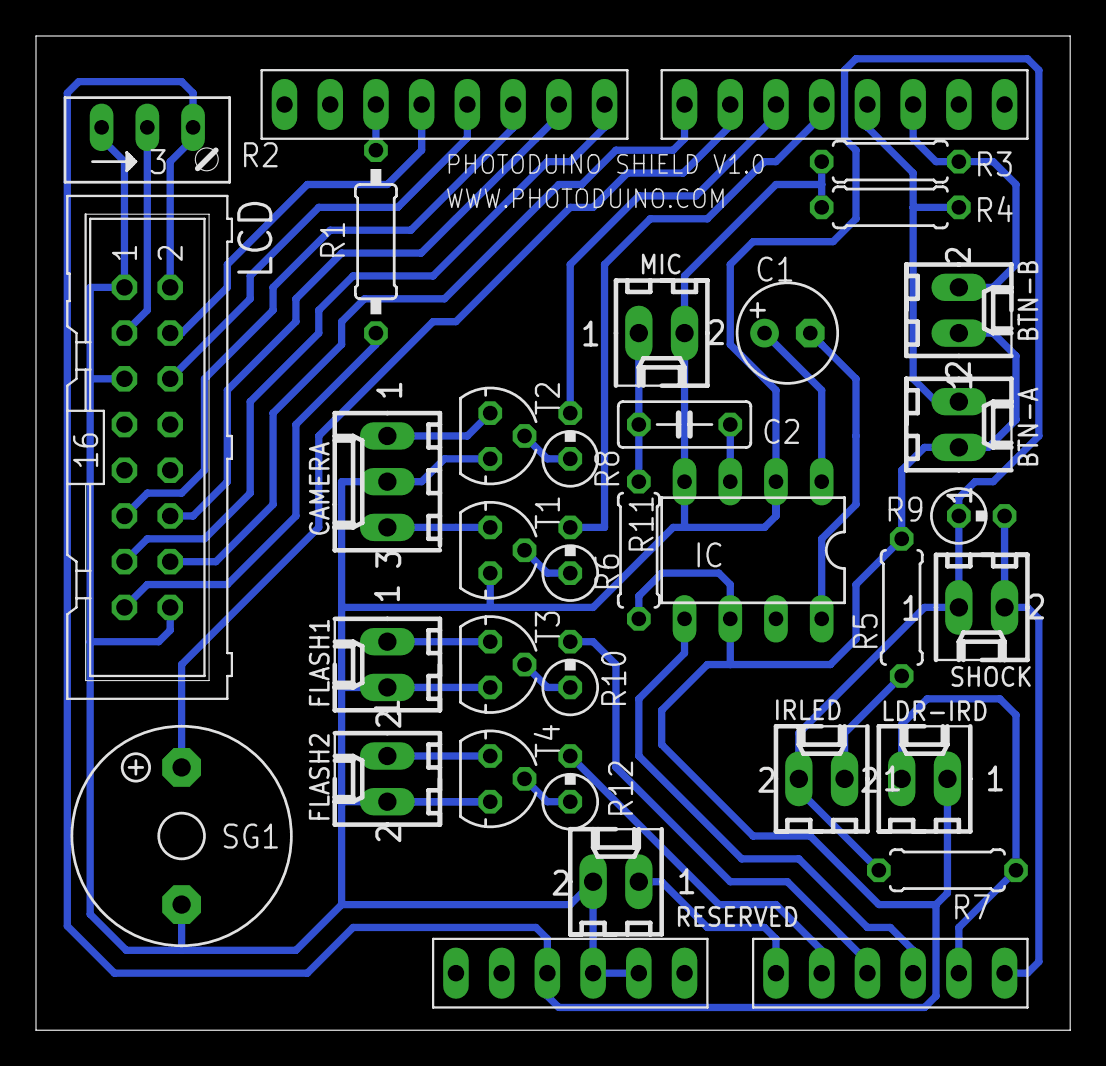
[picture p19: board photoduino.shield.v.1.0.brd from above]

Board: 2 copper layers, 57.5 x 55.2 mm, 32 parts (0 on the bottom side), 35 nets.

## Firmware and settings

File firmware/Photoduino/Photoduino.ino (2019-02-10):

/*
 *             _                          _       _                  
 *            | |           _            | |     (_)                 
 *       ____ | |__   ___ _| |_  ___   __| |_   _ _ ____   ___       
 *      |  _ \|  _ \ / _ (_   _)/ _ \ / _  | | | | |  _ \ / _ \       
 *      | |_| | | | | |_| || |_| |_| ( (_| | |_| | | | | | |_| |      
 *      |  __/|_| |_|\___/  \__)\___/ \____|____/|_|_| |_|\___/       
 *      |_|  THE OPENSOURCE CAMERA CONTROLLER BASED ON ARDUINO         
 *       
 *
 * @name        Photoduino Firmware
 * @version     1.1
 * @web         http://www.photoduino.com
 * @author      http://www.kalanda.com
 *
 * This file is part of Photoduino.
 *
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
 * You should have received a copy of the GNU General Public License
 * along with Photoduino.  If not, see <http://www.gnu.org/licenses/>.
 */

/* ------------------------------------------------------------------------------------------------ *
 *                                         CONFIGURATION VALUES:                                    *
 *                                You can set the next configuration values                         *
 *                                 before compile and upload this sketch                            *
 * ------------------------------------------------------------------------------------------------ */

//
// Language of menus:
// - Set the language of menus in LCD
// 
// Valid values: 
// - "language_EN.h" for (English)
// - "language_ES.h" for (Spanish) 
// - "language_IT.h" for (Italian)
// - "language_FR.h" for (Francais) 
// - "language_DE.h" for (Deutsch) 
//
#define LANGUAGE_FILE "language_EN.h"

//
// Default Camera Shutterlag:
// - The default value for shutterlag to load when you reset config. 
// - Also configurable throught menus.
// 
// Valid values:
// - Number between 0 and 59999 in miliseconds
// - Check your camera model at: http://www.photoduino.com/documentation/reference/cameras-shutterlag/
//
#define DEFAULT_SHUTTERLAG               100 // ms

// 
// Default intercicle time:
// - The default value in miliseconds camera needs to process photo and be ready for the next. 
// - Also configurable throught menus.
// 
// Valid values:
// - Number between 0 and 59999 in miliseconds
//
#define DEFAULT_INTERCYCLE_TIME          200 // ms 

// 
// Default camera mirror lock-up time limit:
// - When use the mirror lock-up shooting mode, all cameras has a limit time (about 30 seconds) to 
//   make the photo while the mirror is locked up. After that time, the mirror is automaticaly unlocked
//   by the camera without taking photo. The next value is this time in miliseconds to say to photoduino 
//   when to re-lock-up the mirror if no photo has taken.  Also configurable throught menus.
// 
// Valid values:
// - Number between 0 and 59999 in miliseconds
//
#define DEFAULT_CAMERA_MIRROR_LOCKUP_TIMEOUT         31000 //ms

// 
// Default device port type:
// - You can set the default device connected to DEVICE port.  Also configurable throught menus.
// 
// Valid values:
// - DEVICE_PORT_TYPE_NONE
// - DEVICE_PORT_TYPE_LASER 
//
#define DEFAULT_DEVICE_PORT_TYPE                DEVICE_PORT_TYPE_NONE    

// 
// Default sensor type:
// - You can set the default sensor type.  Also configurable throught menus.
// 
// Valid values:
// - SENSOR_TYPE_BARRIER
// - SENSOR_TYPE_AUDIO
// - SENSOR_TYPE_LIGHT
// - SENSOR_TYPE_SHOCK
//
#define DEFAULT_SENSOR_TYPE                     SENSOR_TYPE_BARRIER

// 
// Default sensor tunning mode:
// - You can set the default sensor tunning mode.  Also configurable throught menus.
// 
// Valid values:
// - SENSOR_TUNNING_VISUAL
// - SENSOR_TUNNING_NUMERIC
//
#define DEFAULT_SENSOR_TUNING_MODE              SENSOR_TUNING_VISUAL

// 
// Pulse width for shooting flashes:
// - Time in microseconds of the pulse to shoot the flashes.
// - Increase this value if you have problems with your flash model.
// 
// Valid values:
// - Number between 0 and 59999 in microseconds
// 
#define DEVICES_FLASHES_SHOOTING_PULSE     40 // us


//
// Arduino board type:
// - Make the firmware compatible with different boards
// 
// Valid values: 
// - BOARD_ARDUINO_DUEMILANOVE_OR_UNO 
// - BOARD_ARDUINO_MEGA
//
#define BOARD_ARDUINO_DUEMILANOVE_OR_UNO

/* ------------------------------------------------------------------------------------------- *
 *                                     IMPORTANT NOTE:                                         *
 *                        You don't need to modify the code below this lines                   * 
 * ------------------------------------------------------------------------------------------- */

// Fix for Arduino environment
#define prog_char char PROGMEM

// Signature and version codes 
#define SIGNATURE_CODE1             29 // day 
#define SIGNATURE_CODE2             5  // month
#define SIGNATURE_CODE3             20 // century
#define SIGNATURE_CODE4             12 // year of century
#define CODE_MAJOR_VERSION          1  // major version
#define CODE_MINOR_VERSION          1  // minor version

// Default system config
#define DEFAULT_system_useBacklight                   true
#define DEFAULT_system_useSpeaker                     true
#define DEFAULT_system_useFlash1                      true
#define DEFAULT_system_useFlash2                      true
#define DEFAULT_system_sensorTuningMode               DEFAULT_SENSOR_TUNING_MODE
#define DEFAULT_system_cameraShutterLag               DEFAULT_SHUTTERLAG
#define DEFAULT_system_cameraMirrorLockUpTimeout      DEFAULT_CAMERA_MIRROR_LOCKUP_TIMEOUT
#define DEFAULT_system_devicePortType                 DEFAULT_DEVICE_PORT_TYPE

// Default interval mode config
#define DEFAULT_intervalometerMode_autofocusTime      0
#define DEFAULT_intervalometerMode_preFlash1Time      0
#define DEFAULT_intervalometerMode_preFlash2Time      0
#define DEFAULT_intervalometerMode_preCloseTime       0
#define DEFAULT_intervalometerMode_intervalUnits      UNITS_SECS
#define DEFAULT_intervalometerMode_intervalValue      1
#define DEFAULT_intervalometerMode_numCycles          0

// Audio trigger mode default config
#define DEFAULT_sensorTriggerMode_sensorType          DEFAULT_SENSOR_TYPE
#define DEFAULT_sensorTriggerMode_sensorAudioLimit    500
#define DEFAULT_sensorTriggerMode_sensorBarrierLimit  500
#define DEFAULT_sensorTriggerMode_sensorLightLimit    500
#define DEFAULT_sensorTriggerMode_sensorShockLimit    500
#define DEFAULT_sensorTriggerMode_shootingMode        SHOOTINGMODE_NORMAL
#define DEFAULT_sensorTriggerMode_autofocusTime       0
#define DEFAULT_sensorTriggerMode_preFlash1Time       0
#define DEFAULT_sensorTriggerMode_preFlash2Time       0
#define DEFAULT_sensorTriggerMode_preCloseTime        0
#define DEFAULT_sensorTriggerMode_numCycles           0
#define DEFAULT_sensorTriggerMode_interCycleTime      DEFAULT_INTERCYCLE_TIME
#define DEFAULT_sensorTriggerMode_dropsCount          3
#define DEFAULT_sensorTriggerMode_dropsDuration       20
#define DEFAULT_sensorTriggerMode_dropsInterval       1000

// LCD settings
#define LCD_COLS             16 // columns
#define LCD_ROWS             2  // rows

// Pinout settings
#define PINS_LCD_LED         13 //(digital pin)
#define PINS_LCD_RS          12 //(digital pin)
#define PINS_LCD_ENABLE      11 //(digital pin)
#define PINS_LCD_DB4         10 //(digital pin)
#define PINS_LCD_DB5         9  //(digital pin)
#define PINS_LCD_DB6         8  //(digital pin)
#define PINS_LCD_DB7         7  //(digital pin)
#define PINS_BUZZER          6  //(digital pin with pwm)
#define PINS_SHUTTER         5  //(digital pin)
#define PINS_AUTOFOCUS       4  //(digital pin)
#define PINS_BTN_A           3  //(digital pin)
#define PINS_BTN_B           2  //(digital pin)

#define PINS_SENSOR_SHOCK    5  //(analog pin)
#define PINS_SENSOR_BARRIER  4  //(analog pin)
#define PINS_SENSOR_MIC      3  //(analog pin)

#ifdef BOARD_ARDUINO_MEGA    // For ArduinoMega compatibility
  #define PINS_FLASH1        56 // Mega pin 56 = Duemilanove 16 (digital pin)
  #define PINS_FLASH2        55 // Mega pin 55 = Duemilanove 15 (digital pin)
  #define PINS_DEVICE        54 // Mega pin 54 = Duemilanove 14 (digital pin)
#else  
  #define PINS_FLASH1        16 //(digital pin)
  #define PINS_FLASH2        15 //(digital pin)
  #define PINS_DEVICE        14 //(digital pin)
#endif

#define PINS_LASER           PINS_DEVICE  // alias(digital pin)
#define PINS_SOLENOID_VALVE  PINS_DEVICE  // alias(digital pin)

// Sensor types
#define SENSOR_TYPE_NONE                 0 // None sensor
#define SENSOR_TYPE_AUDIO                1 // Audio sensor
#define SENSOR_TYPE_BARRIER              2 // Barrier sensor
#define SENSOR_TYPE_LIGHT                3 // Light sensor
#define SENSOR_TYPE_SHOCK                4 // Shock sensor

// Sensor tunning modes
#define SENSOR_TUNING_VISUAL             0 // Visual 
#define SENSOR_TUNING_NUMERIC            1 // Numeric 

// Sensor limit modes
#define SENSOR_MODE_LOWER                0 // for triggering by lower values
#define SENSOR_MODE_HIGHER               1 // for triggering by higher values

// Shooting modes
#define SHOOTINGMODE_NORMAL              0 // Normal mode 
#define SHOOTINGMODE_PREBULB             1 // Prebulb mode
#define SHOOTINGMODE_MIRRORLOCKUP        2 // Mirror lookup mode

// Device types
#define DEVICE_PORT_TYPE_NONE            0 // None device connected
#define DEVICE_PORT_TYPE_LASER           1 // Laser connected for laser barrier
#define DEVICE_PORT_TYPE_SOLENOID_VALVE  2 // Solenoid valve connected for liquid drops 

// Measurement units
#define UNITS_MS             0  // miliseconds
#define UNITS_SECS           1  // seconds
#define UNITS_MINS           2  // minutes
#define UNITS_HOURS          3  // hours
#define UNITS_DAYS           4  // days
#define UNITS_CYCLES         10 // cycles
#define UNITS_US             11 // microseconds
#define UNITS_DROPS          12 // drops

// Keycodes
#define KEY_NONE             0 // No keys pressed
#define KEY_A                1 // Button A was pressed
#define KEY_B                2 // Button B was pressed
#define KEY_AH               3 // Button A was pressed and holded (KEY_HOLD_TIME) milisecons
#define KEY_BH               4 // Button B was pressed and holded (KEY_HOLD_TIME) milisecons
#define KEY_ABH              5 // Buttons A+B was pressed and holded (KEY_HOLD_TIME) milisecons

// Keyboard times
#define KEY_DEBOUNCE_TIME    30 // debounce time (ms) to prevent flickering when pressing or releasing the button
#define KEY_HOLD_TIME       400 // holding period (ms) how long to wait for press+hold event
#define KEY_HOLD_TIME_WAIT  100 // Used for double key holding

// Characters and symbols addresses on lcd eeprom
#define SYMBOL_DOWN         0x00 // Down arrow
#define SYMBOL_UP           0x01 // Up arrow
#define SYMBOL_BOX          0xff // Black box

// EEPROM size in bytes
#define EEPROM_SIZE         0x200  

// EEPROM Addresses for signature code and version of firmware
#define EE_ADDR_SIGNATURE_CODE1                      0x00 // BYTE
#define EE_ADDR_SIGNATURE_CODE2                      0x01 // BYTE
#define EE_ADDR_SIGNATURE_CODE3                      0x02 // BYTE
#define EE_ADDR_SIGNATURE_CODE4                      0x03 // BYTE
#define EE_ADDR_CODE_MAJOR_VERSION                   0x04 // BYTE
#define EE_ADDR_CODE_MINOR_VERSION                   0x05 // BYTE

// EEPROM Addresses for system config
#define EE_ADDR_system_useBacklight                  0x10 // BYTE
#define EE_ADDR_system_useSpeaker                    0x12 // BYTE
#define EE_ADDR_system_sensorTuningMode              0x14 // BYTE
#define EE_ADDR_system_cameraShutterLag              0x16 // WORD
#define EE_ADDR_system_cameraMirrorLockUpTimeout     0x18 // WORD
#define EE_ADDR_system_useFlash1                     0x1A // BYTE
#define EE_ADDR_system_useFlash2                     0x1C // BYTE
#define EE_ADDR_system_devicePortType                0x1E // BYTE

// EEPROM Addresses for interval mode config
#define EE_ADDR_intervalometerMode_autofocusTime     0x30 // WORD
#define EE_ADDR_intervalometerMode_preFlash1Time     0x32 // WORD
#define EE_ADDR_intervalometerMode_preFlash2Time     0x34 // WORD
#define EE_ADDR_intervalometerMode_preCloseTime      0x36 // WORD
#define EE_ADDR_intervalometerMode_intervalUnits     0x38 // BYTE
#define EE_ADDR_intervalometerMode_intervalValue     0x3A // WORD
#define EE_ADDR_intervalometerMode_numCycles         0x3C // WORD

// EEPROM Addresses for sensor trigger mode config
#define EE_ADDR_sensorTriggerMode_sensorType         0x50 // BYTE
#define EE_ADDR_sensorTriggerMode_sensorAudioLimit   0x52 // WORD
#define EE_ADDR_sensorTriggerMode_sensorBarrierLimit 0x54 // WORD
#define EE_ADDR_sensorTriggerMode_sensorLightLimit   0x56 // WORD
#define EE_ADDR_sensorTriggerMode_sensorShockLimit   0x58 // WORD
#define EE_ADDR_sensorTriggerMode_shootingMode       0x5A // BYTE
#define EE_ADDR_sensorTriggerMode_autofocusTime      0x5C // WORD
#define EE_ADDR_sensorTriggerMode_preFlash1Time      0x5E // WORD
#define EE_ADDR_sensorTriggerMode_preFlash2Time      0x60 // WORD
#define EE_ADDR_sensorTriggerMode_preCloseTime       0x62 // WORD
#define EE_ADDR_sensorTriggerMode_numCycles          0x64 // WORD
#define EE_ADDR_sensorTriggerMode_interCycleTime     0x66 // WORD
#define EE_ADDR_sensorTriggerMode_dropsCount         0x68 // WORD
#define EE_ADDR_sensorTriggerMode_dropsDuration      0x6A // WORD
#define EE_ADDR_sensorTriggerMode_dropsInterval      0x6C // WORD

// Import libraries 
#include <avr/pgmspace.h>  // For messages in flash memory
#include <LiquidCrystal.h> // For LCD Display use 
#include <EEPROM.h>        // For persistent config 
#include "FirmataLite.h"   // For remote control throught USB
#include "Photoduino.h"    // Function prototypes
#include LANGUAGE_FILE     // Messages

// LiquidCrystal LCD control object instance
LiquidCrystal lcd(PINS_LCD_RS, PINS_LCD_ENABLE, PINS_LCD_DB4, PINS_LCD_DB5, PINS_LCD_DB6, PINS_LCD_DB7);

// Variables used on interrupt mode
volatile boolean cancelFlag = false;    // Flag used to abort interrupt mode

// Remote mode variables
boolean remoteMode = false;
boolean remoteSensorBroadcasting = false;
boolean remoteSensorBroadcastingBeepOnLimit = false;

// Global variables
byte         lastKey = KEY_NONE;        // Last key pressed
boolean      flagHoldKey = false;       // Flag to ignore keys after a hold key
byte         lastProgressBarValue = 0;  // Last value of progress bar

// System config in ram
boolean      system_useBacklight;    
boolean      system_useSpeaker;
byte         system_sensorTuningMode;
unsigned int system_cameraShutterLag;
unsigned int system_cameraMirrorLockUpTimeout;
boolean      system_useFlash1;
boolean      system_useFlash2;
byte         system_devicePortType;

// Interval mode config in ram
unsigned int intervalometerMode_autofocusTime;
unsigned int intervalometerMode_preFlash1Time;
unsigned int intervalometerMode_preFlash2Time;
unsigned int intervalometerMode_preCloseTime;
byte         intervalometerMode_intervalUnits;
unsigned int intervalometerMode_intervalValue;
unsigned int intervalometerMode_numCycles;

// Sensor trigger mode config in ram
byte         sensorTriggerMode_sensorType;
unsigned int sensorTriggerMode_sensorAudioLimit;
unsigned int sensorTriggerMode_sensorBarrierLimit;
unsigned int sensorTriggerMode_sensorLightLimit;
unsigned int sensorTriggerMode_sensorShockLimit;
byte         sensorTriggerMode_shootingMode;
unsigned int sensorTriggerMode_autofocusTime;
unsigned int sensorTriggerMode_preFlash1Time;
unsigned int sensorTriggerMode_preCloseTime;
unsigned int sensorTriggerMode_preFlash2Time;
unsigned int sensorTriggerMode_numCycles;
unsigned int sensorTriggerMode_interCycleTime;
unsigned int sensorTriggerMode_dropsCount;
unsigned int sensorTriggerMode_dropsDuration;
unsigned int sensorTriggerMode_dropsInterval;

// Setups at startup
void setup() 
{   
  // Create custom LCD symbols
  byte char_arrow_down[8] = {B00000, B00100, B00100, B00100, B00100, B10101, B01110, B00100};
  byte char_arrow_up[8]   = {B00100, B01110, B10101, B00100, B00100, B00100, B00100, B00000};

  // LCD initialize
  lcd.begin( LCD_COLS,  LCD_ROWS);
  lcd.createChar(SYMBOL_DOWN, char_arrow_down);
  lcd.createChar(SYMBOL_UP, char_arrow_up);

  // Pinmode inputs
  pinMode(PINS_BTN_A,          INPUT);     
  pinMode(PINS_BTN_B,          INPUT);    
  pinMode(PINS_SENSOR_SHOCK,   INPUT); 
  pinMode(PINS_SENSOR_BARRIER, INPUT);
  pinMode(PINS_SENSOR_MIC,     INPUT);  

  // Pinmode outputs
  pinMode(PINS_SHUTTER,        OUTPUT);
  pinMode(PINS_AUTOFOCUS,      OUTPUT);
  pinMode(PINS_FLASH1,         OUTPUT);
  pinMode(PINS_FLASH2,         OUTPUT);
  pinMode(PINS_LCD_LED,        OUTPUT);
  pinMode(PINS_LCD_RS,         OUTPUT);
  pinMode(PINS_LCD_ENABLE,     OUTPUT);
  pinMode(PINS_LCD_DB4,        OUTPUT);
  pinMode(PINS_LCD_DB5,        OUTPUT);
  pinMode(PINS_LCD_DB6,        OUTPUT);
  pinMode(PINS_LCD_DB7,        OUTPUT);
  pinMode(PINS_BUZZER,         OUTPUT);
  pinMode(PINS_DEVICE,         OUTPUT);
  
  // Init Firmata 
  FirmataLite.attach(START_SYSEX, sysexCallback);
  FirmataLite.begin();
}

// Run controller
void loop(){ 
  
  // Initialize config
  config_init(); 

  // Init backlight
  backlight_init();

  // Init device connected to device port
  device_init();
  
  // Run main controller
  controller_run();
 
}

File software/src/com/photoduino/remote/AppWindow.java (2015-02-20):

package com.photoduino.remote;

import java.io.FileNotFoundException;
import java.io.IOException;
import java.io.InputStream;
import java.util.Properties;

import org.apache.log4j.Logger;

import org.eclipse.swt.widgets.Display;
import org.eclipse.swt.widgets.Shell;
import org.eclipse.swt.widgets.Button;
import org.eclipse.swt.SWT;
import org.eclipse.swt.events.DisposeEvent;
import org.eclipse.swt.events.DisposeListener;
import org.eclipse.swt.layout.GridLayout;
import org.eclipse.swt.widgets.Composite;
import org.eclipse.swt.widgets.Label;
import org.eclipse.swt.widgets.Combo;
import org.eclipse.swt.layout.GridData;
import org.eclipse.swt.widgets.Event;
import org.eclipse.swt.widgets.Listener;
import org.eclipse.swt.widgets.TabFolder;
import org.eclipse.swt.widgets.TabItem;
import org.eclipse.swt.widgets.Spinner;
import org.eclipse.swt.widgets.Group;
import org.eclipse.swt.events.SelectionListener;
import org.eclipse.swt.events.SelectionEvent;

import com.photoduino.remote.swt.widgets.SensorBar;
import org.eclipse.swt.events.MouseListener;
import org.eclipse.swt.events.MouseEvent;
import org.eclipse.swt.graphics.Color;


public class AppWindow implements SelectionListener, PhotoduinoEventListener, MouseListener {
	
	private static final int SERIAL_PORTS_UPDATE_FREQ = 1000;
	
	private Properties appConfig;
	private PhotoduinoSerialManager serialManager;
	private Logger logger = Logger.getLogger(getClass());
	private PhotoduinoConfig photoduinoConfig = new PhotoduinoConfig();
	private int lastSensorRead = 0;
	private Boolean lastSensorOverflow = false;
	private BusyDialog busyDialog = null;
	
	protected Shell shell;
	private Composite connectionPanel;
	private Label serialPortListLabel;
	private Combo serialPortListCombo;
	private Button connectButton;
	private TabFolder tabsPanel;
	private TabItem system_tabItem;
	private Composite system_tabPanel;
	private Label system_devicePortTypeLabel;
	private Combo system_devicePortType;
	private Label system_sensorTuningModeLabel;
	private Combo system_sensorTuningMode;
	private Label system_cameraShutterLagLabel;
	private Spinner system_cameraShutterLag;
	private Label system_cameraMirrorLockUpTimeoutLabel;
	private Spinner system_cameraMirrorLockUpTimeout;
	private TabItem intervalometerMode_tabItem;
	private Composite intervalometerMode_tabPanel;
	private Label intervalometerMode_autofocusTimeLabel;
	private Spinner intervalometerMode_autofocusTime;
	private Spinner intervalometerMode_preFlash1Time;
	private Label intervalometerMode_preFlash1TimeLabel;
	private Label intervalometerMode_preFlash2TimeLabel;
	private Spinner intervalometerMode_preFlash2Time;
	private Label intervalometerMode_preCloseTimeLabel;
	private Spinner intervalometerMode_preCloseTime;
	private Combo intervalometerMode_intervalUnits;
	private Spinner intervalometerMode_intervalValue;
	private Label intervalometerMode_intervalLabel;
	private Spinner intervalometerMode_numCycles;
	private Label intervalometerMode_numCyclesLabel;
	private TabItem sensorTrigger_tabItem;
	private Composite sensorTrigger_tabPanel;
	private Group sensorTrigger_sensorGroup;
	private Combo sensorTriggerMode_sensorType;
	private Label sensorTriggerMode_sensorTypeLabel;
	private Spinner sensorTriggerMode_sensorLimit;
	private Label sensorTriggerMode_sensorLimitLabel;
	private Group sensorTrigger_dropsConfigGroup;
	private Label sensorTriggerMode_dropsCountLabel;
	private Spinner sensorTriggerMode_dropsCount;
	private Label sensorTriggerMode_dropsDurationLabel;
	private Spinner sensorTriggerMode_dropsDuration;
	private Label sensorTriggerMode_dropsIntervalLabel;
	private Spinner sensorTriggerMode_dropsInterval;
	private Button sensorTriggerMode_testDropsButton;
	private Label sensorTriggerMode_dropsCountUnitsLabel;
	private Label sensorTriggerMode_dropsDurationUnitsLabel;
	private Label sensorTriggerMode_dropsIntervalUnitsLabel;
	private Button sensorTrigger_runButton;
	private Group sensorTrigger_lifeCycleGroup;
	private Label sensorTriggerMode_autofocusTimeLabel;
	private Label sensorTriggerMode_shootingModeLabel;
	private Combo sensorTriggerMode_shootingMode;
	private Spinner sensorTriggerMode_autofocusTime;
	private Label sensorTriggerMode_autofocusTimeUnitsLabel;
	private Label sensorTriggerMode_preFlash1TimeLabel;
	private Spinner sensorTriggerMode_preFlash1Time;
	private Label sensorTriggerMode_preFlash1TimeUnitsLabel;
	private Label sensorTriggerMode_preFlash2TimeLabel;
	private Spinner sensorTriggerMode_preFlash2Time;
	private Label sensorTriggerMode_preFlash2TimeUnitsLabel;
	private Label sensorTriggerMode_preCloseTimeLabel;
	private Spinner sensorTriggerMode_preCloseTime;
	private Label sensorTriggerMode_preCloseTimeUnitsLabel;
	private Label sensorTriggerMode_numCyclesLabel;
	private Spinner sensorTriggerMode_numCycles;
	private Label sensorTriggerMode_numCyclesUnitsLabel;
	private Label sensorTriggerMode_interCycleTimeLabel;
	private Spinner sensorTriggerMode_interCycleTime;
	private Label sensorTriggerMode_interCycleTimeUnitsLabel;
	private Group intervalometerMode_lifeCycleGroup;
	private Label intervalometerMode_autofocusTimeUnitsLabel;
	private Label intervalometerMode_preFlash1TimeUnitsLabel;
	private Label intervalometerMode_preFlash2TimeUnitsLabel;
	private Label intervalometerMode_preCloseTimeUnitsLabel;
	private Label intervalometerMode_numCyclesUnitsLabel;
	private Group system_defaultGroup;
	private Label system_cameraShutterLagUnitsLabel;
	private Label system_cameraMirrorLockUpTimeoutUnitsLabel;
	private Button intervalometerMode_runButton;
	private Label statusBar;
	private Label system_useFlash1Label;
	private Label system_useFlash2Label;
	private Label system_useSpeakerLabel;
	private Label system_useBacklightLabel;
	private SensorBar sensorTriggerMode_sensorBar;
	private TabItem manualControl_tabItem;
	private Composite manualControl_tabPanel;
	private Group manualControl_cameraGroup;
	private Button manualControl_shutterButton;
	private Button manualControl_autofocusButton;
	private Button manualControl_autofocusAndShutterButton;
	private Group manualControl_flashesGroup;
	private Button manualControl_flash1Button;
	private Button manualControl_flash2Button;
	private Group manualControl_solenoidValveGroup;
	private Button manualControl_solenoidValveButton;
	private Button system_useFlash1;
	private Button system_useFlash2;
	private Button system_useSpeaker;
	private Button system_useBacklight;
	private Button sensorBeepOnLimit;
	private Composite statusBarPanel;
	private Label statusLabel;
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

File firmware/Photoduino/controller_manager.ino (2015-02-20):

/*
 * This file is part of Photoduino.
 *
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
 * You should have received a copy of the GNU General Public License
 * along with Photoduino.  If not, see <http://www.gnu.org/licenses/>.
 */

// Runs the controller
void controller_run(){

   controller_showWelcome();
   remote_sendReady();
   
   while(true) {
     
     keyboard_scan();
     
     if(lastKey != KEY_NONE) {
        controller_showMainMenu();
        controller_showWelcome();
     }
     
     if(FirmataLite.available()) FirmataLite.processInput();
     
     if(remoteMode){
       controller_showRemoteMode();
       while(remoteMode){
          if(FirmataLite.available()) FirmataLite.processInput();
          remote_sensor_broadcast();
       }
       controller_showWelcome();
     }
   }
}

// Show remote mode
void controller_showRemoteMode(){
   lcd.clear();
   display_printMessage(MSG_REMOTE_MODE);
}

// Show welcome
void controller_showWelcome(){
   lcd.clear();
   display_printMessage(MSG_PHOTODUINO_V);
   lcd.print(CODE_MAJOR_VERSION,10);
   lcd.print(".");
   lcd.print(CODE_MINOR_VERSION,10);
   lcd.setCursor(0,1);
   display_printMessage(MSG_READY);
   buzzer_beep(200);
}

// Main Menu View
void controller_showMainMenu(){
  
  byte currentOption = 0;
  
  for(boolean exit = false;!exit;){
      
    display_printTitle(MSG_MAIN_MENU);

    if(currentOption==0) display_printEnumeration(0, MSG_SYSTEM_CONFIG); 
    if(currentOption==1) display_printEnumeration(1, MSG_INTERVALOMETER); 
    if(currentOption==2) display_printEnumeration(2, MSG_SENSOR_TRIGGER);
    
    keyboard_waitForAnyKey();
    
    if(lastKey==KEY_A) circularList_incrementBy(&currentOption, 0, 2, -1);   
    if(lastKey==KEY_B) circularList_incrementBy(&currentOption, 0, 2, 1);        
    if(lastKey==KEY_AH) exit = true;
    if(lastKey==KEY_BH) {
                        
          if(currentOption==0) controller_showSystemConfig(); 
          if(currentOption==1) controller_showIntervalMenu(); 
          if(currentOption==2) controller_showSensorTriggerMenu();
    }
  }
}

// Interval Menu View
void controller_showIntervalMenu(){
  
  byte currentOption = 0;
 
  for(boolean exit = false;!exit;){
      
    display_printTitle(MSG_INTERVALOMETER);

    // Show menu option
    if(currentOption==0) display_printMessage(MSG_CONFIG);
    if(currentOption==1) display_printMessage(MSG_RUN);
    if(currentOption==2) display_printMessage(MSG_RESET_CONFIG);
    
    keyboard_waitForAnyKey();
    
    if(lastKey==KEY_A) circularList_incrementBy(&currentOption, 0, 2, -1);        
    if(lastKey==KEY_B) circularList_incrementBy(&currentOption, 0, 2, 1);   
    if(lastKey==KEY_AH) exit = true;
    if(lastKey==KEY_BH) {
                    
         if(currentOption==0)  { controller_showIntervalConfig(); } 
         if(currentOption==1)  { runAs_intervalometer(); }
         if(currentOption==2)  { if(controller_confirmAction(MSG_RESET_CONFIG)) {config_loadDefaults_intervalometerMode(); config_saveBackup_intervalometerMode(); display_printResetting(); } }
    }
  }
}

// Sensor trigger menu view
void controller_showSensorTriggerMenu(){
  
  byte currentOption = 0;
  boolean skipOption = false;
  
  for(boolean exit = false;!exit;){
      
    display_printTitle(MSG_SENSOR_TRIGGER);

    // Show menu option
    if(currentOption==0) display_printMessage(MSG_CONFIG_TRIGGER);
    if(currentOption==1) { if(system_devicePortType==DEVICE_PORT_TYPE_SOLENOID_VALVE) display_printMessage(MSG_CONFIG_DROPS); else skipOption = true; }
    if(currentOption==2) display_printMessage(MSG_RUN);
    if(currentOption==3) display_printMessage(MSG_RESET_CONFIG);
    
    if (!skipOption) keyboard_waitForAnyKey();
    else skipOption = false;
      
    if(lastKey==KEY_A) { circularList_incrementBy(&currentOption, 0, 3, -1); }
    if(lastKey==KEY_B) { circularList_incrementBy(&currentOption, 0, 3, 1); }
    if(lastKey==KEY_AH) exit = true;
    if(lastKey==KEY_BH) {
                    
           if(currentOption==0) { controller_showSensorTriggerConfig(); } 
           if(currentOption==1) { controller_showDropsConfig(); } 
           if(currentOption==2) { runAs_sensorTriggerMode(); }
           if(currentOption==3) { if(controller_confirmAction(MSG_RESET_CONFIG)) {config_loadDefaults_sensorTriggerMode(); config_saveBackup_sensorTriggerMode(); display_printResetting();} }
    }
    
  }
}


// System config View
void controller_showSystemConfig(){
  
  byte currentOption = 0;
 
  for(boolean exit = false;!exit;){
      
    display_printTitle(MSG_SYSTEM_CONFIG);

    // Show menu option
    if(currentOption==0) { display_printMessage(MSG_DEVICE_PORT_TYPE); }
    if(currentOption==1) { display_printMessage(MSG_SENSOR_TUNING); }
    if(currentOption==2) { display_printMessage(MSG_SHUTTERLAG_TIME); }
    if(currentOption==3) { display_printMessage(MSG_MIRROR_LOCKUP_TIMEOUT); }
    if(currentOption==4) { display_printMessage(MSG_USE_FLASH1); display_printBoolean(system_useFlash1); }
    if(currentOption==5) { display_printMessage(MSG_USE_FLASH2); display_printBoolean(system_useFlash2); }
    if(currentOption==6) { display_printMessage(MSG_SPEAKER); display_printBoolean(system_useSpeaker); }
    if(currentOption==7) { display_printMessage(MSG_BACKLIGHT); display_printBoolean(system_useBacklight); }

    
    keyboard_waitForAnyKey();
    
    if(lastKey==KEY_A) circularList_incrementBy(&currentOption, 0, 7, -1);
    if(lastKey==KEY_B) circularList_incrementBy(&currentOption, 0, 7, 1);
    if(lastKey==KEY_AH) { config_saveBackup_system(); exit = true; } 
    if(lastKey==KEY_BH) {
          
          if(currentOption==0) controller_setDevicePortType(&system_devicePortType);
          if(currentOption==1) controller_setSensorTuningMode(&system_sensorTuningMode);
          if(currentOption==2) controller_setNumericParameterValue(&system_cameraShutterLag, MSG_SHUTTERLAG_TIME, UNITS_MS);
          if(currentOption==3) controller_setNumericParameterValue(&system_cameraMirrorLockUpTimeout, MSG_MIRROR_LOCKUP_TIMEOUT,UNITS_MS);
          if(currentOption==4) system_useFlash1 = !system_useFlash1;
          if(currentOption==5) system_useFlash2 = !system_useFlash2;       
          if(currentOption==6) system_useSpeaker = !system_useSpeaker;
          if(currentOption==7) backlight_toggle();     
          
    }
  }
}
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

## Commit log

2015-02-20 Added logos and case files
2015-05-23 Fixed CODE_MINOR_VERSION to the real version (1.1)
    [Photoduino.ino]
2019-02-10 Added function prototypes to fix latest Arduino IDE compilation errors
    [Photoduino.ino]

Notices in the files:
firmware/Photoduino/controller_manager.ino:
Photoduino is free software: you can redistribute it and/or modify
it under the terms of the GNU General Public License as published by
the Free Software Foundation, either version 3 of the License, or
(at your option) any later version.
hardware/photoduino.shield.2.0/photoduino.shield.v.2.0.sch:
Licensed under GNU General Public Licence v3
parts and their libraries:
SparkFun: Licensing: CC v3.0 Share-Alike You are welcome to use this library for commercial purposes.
